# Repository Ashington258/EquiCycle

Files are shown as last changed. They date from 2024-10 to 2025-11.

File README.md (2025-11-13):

# README

本工程是参与全国大学生智能车竞赛室外赛自行车赛道的开源工程。(曾获得智能车竞赛国一)

## 1. 工程结构说明

本项目储存了关于平衡自行车项目所需要的所有源代码，以及硬件架构和软件架构。下面是关于自行车项目的工程结构说明：

1. **main分支**：汇总存放代码
2. **Calculation_Unit分支**：计算单元代码，主要存放关于车道线检测、障碍物识别以及决策类的处理，是系统总计算单元的主要部分。
3. **Control_Unit分支**：控制单元代码，主要存放关于控制模块，负责车身的平衡、转向、前进和后退等运动学操作。
4. **Mechanical_Unit分支**：机械单元分支，主要包含车身的机械结构，用于CNC加工和3D打印等。

> 注：`beta`分支为测试版本代码。

## 2. 实现功能

### 2.1 视觉模块

#### 抗干扰测试（交叉线，阴影）
抗干扰测试

#### 光线变化测试

1. **强光测试**
   强光测试

2. **弱光测试**
   弱光测试

### 2.2 运动学模块

运动学模块
1. 遥感控制/键盘控制
2. 自动控制(PID,LQR)

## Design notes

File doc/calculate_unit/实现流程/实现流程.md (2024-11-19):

# 设计流程

根据架构，工作主要分为Jetson端和Host端的工作

要同时实现Video视频流和Servo控制流，具体程序主要分为Jetson端和Host端，并且需要考虑多线程同步的问题。

- 按任务实现
  - [ ] Video视频流
    - [x] Jetson端
      - [ ] 完成Flask推流
    - [ ] Host端
      - [ ] 完成拉流
  - [ ] Servo控制流
    - [ ] Host端
      - [ ] 计算出的点映射成舵机脉冲
      - [ ] 转化成Servo控制流
      - [ ] UDP发送Servo控制流
    - [ ] Jetson端
      - [ ] 接收Servo控制流
      - [ ] 通过Pyserial转发到串口

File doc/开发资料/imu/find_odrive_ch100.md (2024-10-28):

要将 `/dev/ttyUSB0` 和 `/dev/ttyACM0` 设备与相应的 USB 设备 ID（例如 `10c4:ea60` 和 `1209:0d32`）对应起来，可以使用以下步骤：

### 步骤 1: 确认设备

首先，确保你已经插入了 USB 设备，并使用 `lsusb` 命令确认设备 ID：

```bash
lsusb
```

这将列出所有连接的 USB 设备及其 ID。

### 步骤 2: 使用 `dmesg` 查看设备信息

插入 USB 设备后，使用 `dmesg` 查看设备相关信息：

```bash
dmesg | grep tty
```

这将显示设备连接时的相关信息，包括设备节点（如 `/dev/ttyUSB0` 或 `/dev/ttyACM0`）和设备的 USB ID。

### 步骤 3: 识别设备与串口的对应关系

1. **查看 `dmesg` 输出**：查找在插入设备后产生的输出，通常会显示类似以下格式的信息：

   ```
   [    3.123456] usb 1-1.2: cp210x converter now attached to ttyUSB0
   [    3.123456] usb 1-1.3: pl2303 converter now attached to ttyUSB1
   ```

   这里可以看到 `cp210x` 设备（对应于 `10c4:ea60`）被分配到 `/dev/ttyUSB0`。

2. **使用 `udevadm` 查看设备信息**：你可以使用 `udevadm` 命令来获取更详细的信息：

   ```bash
   udevadm info --name=/dev/ttyUSB0 --attribute-walk
   ```

   这个命令将显示与 `/dev/ttyUSB0` 相关的所有属性，包括 USB ID。

### 步骤 4: 结合信息

通过上述步骤，你可以将设备 ID 与 `/dev/ttyUSB0` 和 `/dev/ttyACM0` 进行对应。例如：

- 如果你看到 `ttyUSB0` 显示的信息中包含 `10c4:ea60`，那么 `/dev/ttyUSB0` 对应于 `CP2102N USB to UART Bridge Controller`。
- 如果 `ttyACM0` 显示的信息中包含 `1209:0d32`，那么 `/dev/ttyACM0` 对应于 `ODrive 3.6 CDC Interface`。

### 示例

假设你在 `dmesg` 输出中看到：

```
[    3.123456] usb 1-1.2: new full-speed USB device number 4 using xhci_hcd
[    3.123456] usb 1-1.2: New USB device found, idVendor=10c4, idProduct=ea60
[    3.123456] usb 1-1.2: cp210x converter now attached to ttyUSB0
```

这表明 `10c4:ea60` 的设备被分配给了 `/dev/ttyUSB0`。

### 总结

通过 `dmesg` 和 `udevadm` 命令，你可以有效地将 `/dev/ttyUSB0` 和 `/dev/ttyACM0` 与相应的 USB 设备 ID 进行对应。如果你有其他问题或需要进一步的帮助，请告诉我！

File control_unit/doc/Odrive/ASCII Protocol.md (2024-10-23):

Here’s a summary of the protocol layers based on the given ASCII protocol, encapsulated in a Python class for ease of use.

### ASCII Protocol Summary
1. **Communication Interfaces**: 
   - USB or UART can be used to communicate with the ODrive. Different commands are sent based on the connection type.

2. **Command Format**:
   - Commands are sent as text-based lines, potentially including an optional GCode-compatible checksum.
   - The format is: `command *checksum ; comment [newline]`.
   - Commands are interpreted when a newline character is encountered.

3. **Command Types**:
   - **Motor Commands**:
     - `t motor destination`: Motor trajectory command.
     - `q motor position velocity_lim torque_lim`: Single setpoint for motor position.
     - `p motor position velocity_ff torque_ff`: Streaming setpoints for motor position.
     - `v motor velocity torque_ff`: Motor velocity command.
     - `c motor torque`: Motor current (torque) command.
   - **Feedback Requests**:
     - `f motor`: Requests motor position and velocity feedback.
   - **Watchdog Update**:
     - `u motor`: Updates the motor watchdog timer.
   - **Parameter Reading/Writing**:
     - `r property`: Read parameter.
     - `w property value`: Write parameter.
   - **System Commands**:
     - `ss`: Save configuration.
     - `se`: Erase configuration.
     - `sr`: Reboot.
     - `sc`: Clear errors.

### Python Encapsulation

The following Python class encapsulates the described ASCII protocol:

```python
import serial

class ODriveAsciiProtocol:
    def __init__(self, port: str, baudrate: int = 115200):
        self.serial = serial.Serial(port, baudrate, timeout=1)

    def send_command(self, command: str):
        # Send command to the ODrive, with newline character
        self.serial.write(f"{command}\n".encode())

    def read_response(self):
        # Read the response from ODrive
        return self.serial.readline().decode().strip()

    def motor_trajectory(self, motor: int, destination: float):
        command = f"t {motor} {destination}"
        self.send_command(command)

    def motor_position(self, motor: int, position: float, velocity_lim: float = None, torque_lim: float = None):
        command = f"q {motor} {position}"
        if velocity_lim is not None:
            command += f" {velocity_lim}"
        if torque_lim is not None:
            command += f" {torque_lim}"
        self.send_command(command)

    def motor_position_stream(self, motor: int, position: float, velocity_ff: float = 0.0, torque_ff: float = 0.0):
        command = f"p {motor} {position} {velocity_ff} {torque_ff}"
        self.send_command(command)

    def motor_velocity(self, motor: int, velocity: float, torque_ff: float = 0.0):
        command = f"v {motor} {velocity} {torque_ff}"
        self.send_command(command)

    def motor_current(self, motor: int, torque: float):
        command = f"c {motor} {torque}"
        self.send_command(command)

    def request_feedback(self, motor: int):
        command = f"f {motor}"
        self.send_command(command)
        return self.read_response()

    def update_watchdog(self, motor: int):
        command = f"u {motor}"
        self.send_command(command)

    def read_parameter(self, property_name: str):
        command = f"r {property_name}"
        self.send_command(command)
        return self.read_response()

    def write_parameter(self, property_name: str, value: float):
        command = f"w {property_name} {value}"
        self.send_command(command)

    def system_command(self, command_type: str):
        valid_commands = {"ss", "se", "sr", "sc"}
        if command_type not in valid_commands:
            raise ValueError(f"Invalid system command: {command_type}")
        self.send_command(command_type)

    def close(self):
        self.serial.close()
```

### Usage Example
```python
# Example usage
odrive = ODriveAsciiProtocol(port='/dev/ttyACM0')
odrive.motor_position(0, -2, velocity_lim=1, torque_lim=0.1)
feedback = odrive.request_feedback(0)
print(f"Motor feedback: {feedback}")
odrive.close()
```

This class provides a Pythonic way to interact with the ODrive via the ASCII protocol, supporting motor control, parameter management, and system operations.

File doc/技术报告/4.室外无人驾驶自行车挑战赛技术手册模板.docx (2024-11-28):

第十九届全国大学生智能汽车竞赛

室外无人驾驶自行车挑战赛

技 术 手 册

学 校：XXXX学院

队伍名称：XX

参赛队员：XX、XX、XX

带队教师：XX、XX

关于技术手册使用授权的说明

本人完全了解全国大学生智能汽车竞赛关于保留、使用技术手册和研究论文的规定，即：参赛技术手册内容著作权归参赛者本人，比赛组委会和赞助公司可以在相关主页上收录并公开参赛作品的设计方案、技术手册、源码以及参赛模型车的视频、图像资料，并将相关内容编纂收录在组委会出版论文集中。

参赛队员签名：

带队教师签名：

日 期： 2024.**.**

（本页需要签字后，替换为扫描页）

## 技术手册撰写注意事项：

了解到实验室队伍老生带新生容易断带、知识不能很好的积累沉淀转化等痛点，本次技术手册的内容更加聚焦于技术总结，知识整理。力图将技术手册打造为老队员、新队员、指导老师之间共用的知识纽带。通过几年的打磨，便于带队老师开设自动化控制、自动驾驶、人工智能、软件编程等相关课程以及开展新队员的筛选工作，便于新队员更快的传承已有的知识储备，使得实验室队伍建设构成闭环。

技术手册内容主要是将自行车作为硬件载体，以自动化控制、自动驾驶、人工智能、软件编程等专业为导向，构建一套用于学习的实验指导书。书写的内容结合车模配套的指导手册、视频资料以及比赛规则。

技术手册书写注意事项如下：

(1) 提交形式为实验指导书+源码；

(2) 所有内容，需要以自行车作为唯一硬件载体；

(3) 提供不少于3个实验，以实验指导书+源码的形式提交；

(4) 裁判将结合实验难易程度、书写清晰度、实验个数、实验间是否有关联性等多种因素，决定本技术手册的优劣。

技术手册总分10分，评判标准如下：

(1)每个实验最高分5分，总体不少于2个实验；

(2)每个实验得分根据实验难易程度、书写清晰度、实验间是否有关联性、创新性等因素进行判定；

(3)若书写多于2个实验，逐个实验判分后，以分数最高的2个实验的成绩加和作为最终成绩。

### 目录（供参考）

实验一 单片机设计原理 2

实验二 供电系统设置 4

实验三 电机调节步骤及参数解析 6

实验四 PID算法调试 8

实验五 激光雷达数据结构分析及滤波 10

实验六 视觉功能调试 12

实验七 opencv数据处理 14

实验八 机器人运动学平台 16

(以上目录仅供参考，具体实验名称及实验内容由学生自主设定)

实验案例书写具体要求如下：

实验案例需言简意赅，便于后续师弟师妹消化传承；

实验案例撰写可自行创新发挥，新颖的案例更加容易获得高分；

每个实验需要包含实验目的、实验内容、实验器材、实验原理、实验步骤这几部分；

实验目的：参考模板，提炼若干条

实验内容：针对实验目的，开展的具体操作总结

实验器材：罗列实验中用到的器材设备、传感器、工具、测量仪器等

实验原理：描述实验中硬件实现原理、物理相关基础、算法实现原理等

实验步骤：实验开展过程中具体的运行指令、操作方式、测试方式、代码讲解等

### 实验五 激光雷达数据结构分析及滤波(参考样例)

#### 实验目的：

1、熟悉激光雷达数据结构；

2、了解激光雷达数据的处理方法；

3、熟练掌握laser_filters功能包的使用；

#### 实验内容：

1、获取并分析激光雷达数据；

2、对激光雷达数据进行滤波处理。

#### 实验仪器：

ROS智能车、激光雷达、电压表

#### 实验原理：

利用laser_filters功能包，对雷达数据进行处理，得到需要的滤波后的雷达数据。

#### 实验步骤：

<1> 启动雷达，并获取雷达数据(需要先编译我的功能包，并加入环境变量)

$ roslaunch ls0lb_v2 ls01b_v2.launch

启动后的效果如下图所示，这个时候就启动了雷达节点和滤波节点，具体为什么会启动，已经如何配置launch文件里那些参数，后面会讲到。首先我们先来看一下雷达的原始数据，分析一下雷达数据结构。

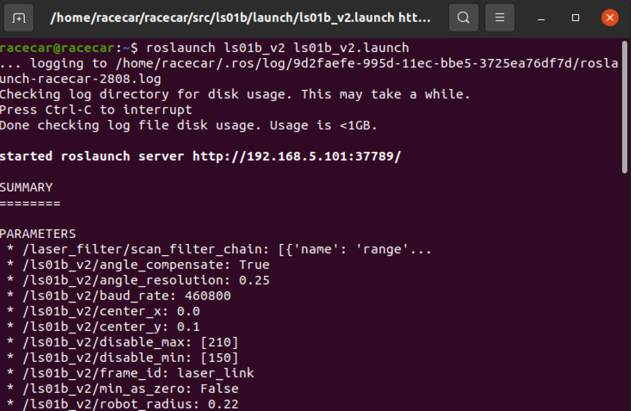
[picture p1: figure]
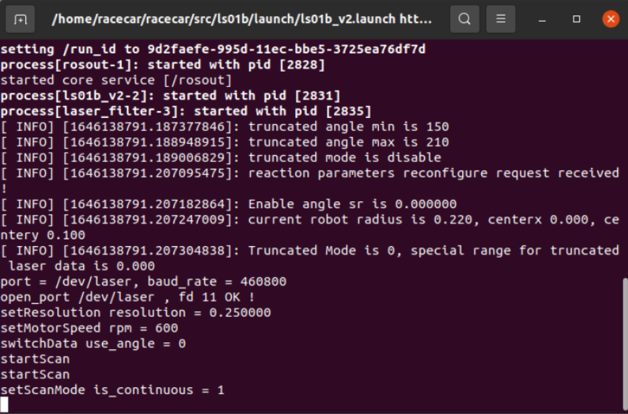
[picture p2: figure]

<2> 打印雷达数据消息，并分析雷达数据(新开一个终端输入下面命令)

$ rostopic echo /scan

运行后会如下图所示，不断打印雷达数据。

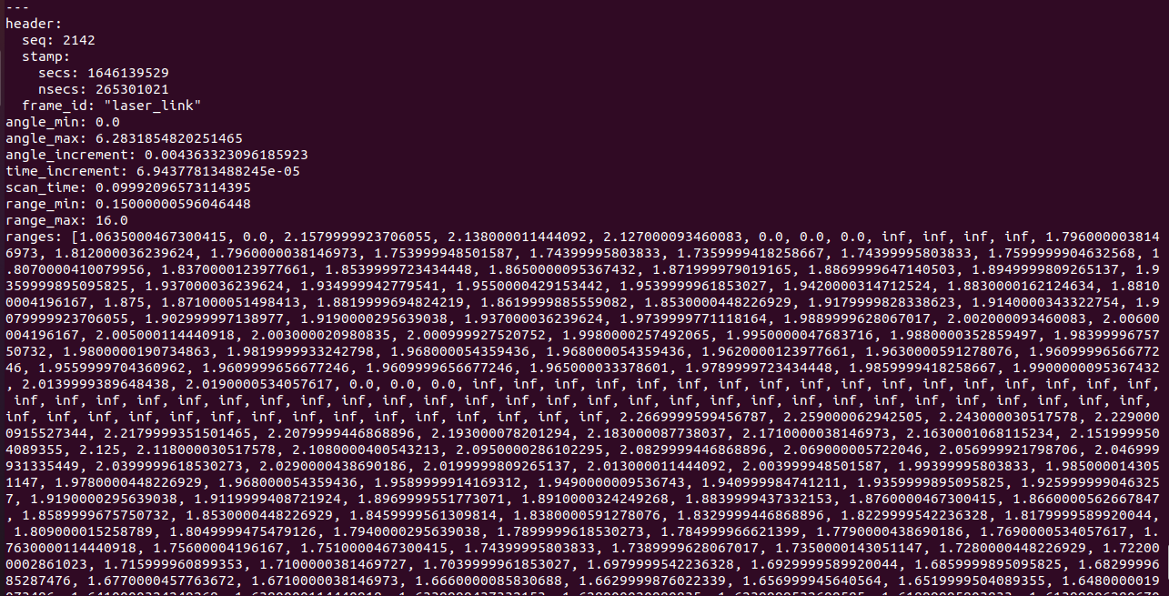
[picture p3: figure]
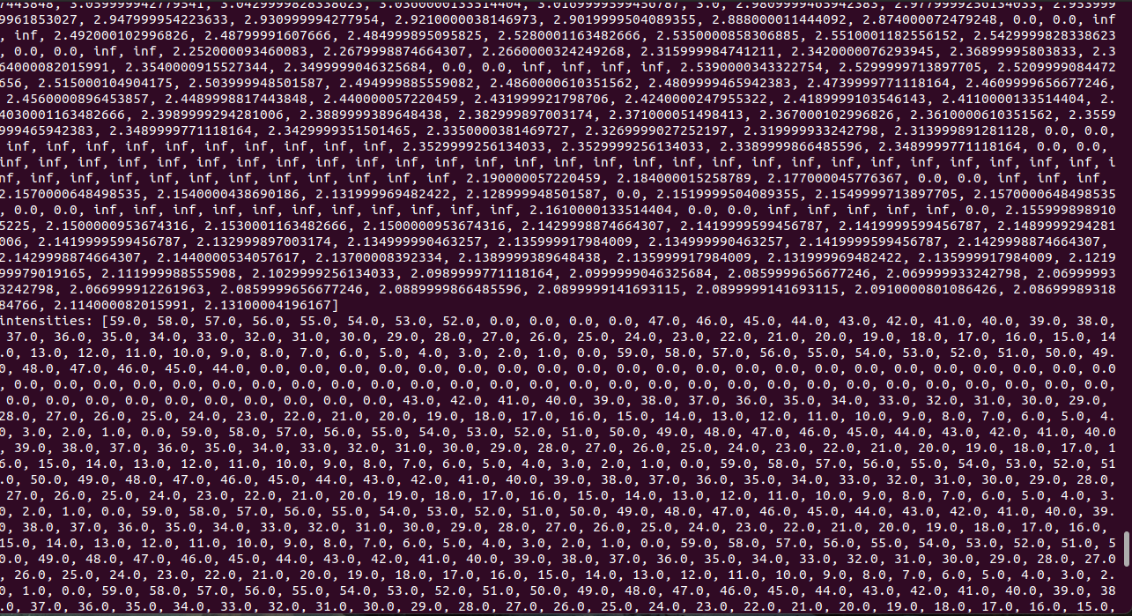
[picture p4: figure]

下面我们来看一下雷达数据结构：

激光雷达是避障与SLAM常用的装备，ROS中也对激光雷达作出了相应的支持，各个厂家也有不少提供了自己的ROS库供开发者使用，使得无论是初学者还是大神们都能轻松愉快的使用激光雷达为自己的机器人导航。

ROS中的sensor_msgs/LaserScan提供了最基础的针对一线激光雷达消息格式：

# 一线激光雷达的一次扫描

Header header # timestamp是扫描中第一束激光的获取时间

# 角度环绕Z轴（Z轴为激光雷达正上方），逆时钟方向增加，0度角指向X轴

float32 angle_min # 扫描的起始角度 [rad]

float32 angle_max # 扫描的结束角度 [rad]

float32 angle_increment # 每次测量间的角度差 [rad]

float32 time_increment # 每次测量间的时间差 [seconds]

# 这个数值会用来生成点云（而不是scan_time）

float32 scan_time # 每次扫描的时间差 [seconds]

# 这个时间差是每次激光发射的时间差，上面那个是每次接收（测量）的时间差

float32 range_min # 距离最小值 [m]

float32 range_max # 距离最大值 [m]

float32[] ranges # 距离数据 [m]

float32[] intensities # 强度数据 [单位视设备标定]

#如果设备不产生强度数据，则该数据为空

对应前面的雷达数据，我们可以将sensor_msgs/LaserScan消息和智能车雷达数据一一对应起来，我重点讲的是range数据，因为后面实验三会用到。

range是数组，数组的长度越长，说明激光雷达的精度越高，咱们的智能车的range数组长度是1140，也就是一周每一度都有4份距离信息。

range数组是如何和角度对应的呢？range[0]对应的角度就是激光雷达的零点方向（一般为激光雷达的正前方），后面数据rangep[1]、range[2]……依次为沿激光雷达逆时针方向对应角度的距离数据。

<3> 使用laser_filters对雷达数据进行滤波

$ laser_filters的wiki页 (http://wiki.ros.org/laser_filters)

http://wiki.ros.org/laser_filters

在yaml文件里面定义了很多laser_filters消息的参数后，通过启动laser_filters节点完成激光雷达消息的过滤。其中scan_to_scan_filter_chain提供了从初始扫描到过滤后扫描的流程：

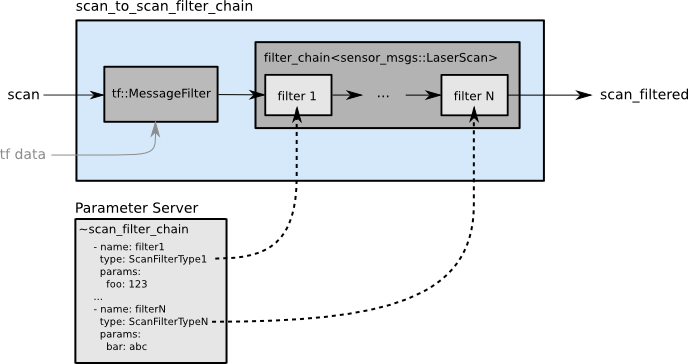
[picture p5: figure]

而scan_to_cloud_filter_chain提供了从scan消息生成过滤后的点云的流程：

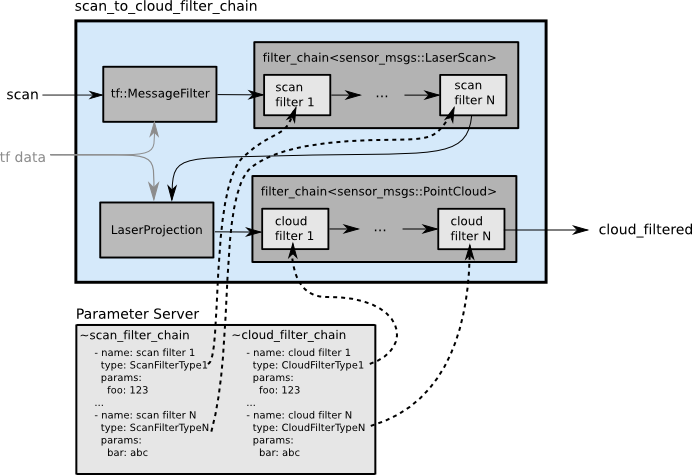
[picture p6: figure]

这两类的示例yaml和launch都可以在上面提供的wiki页找到，很有参考价值的（基本上拷下来调调参数就能用了）设置参数放在yaml里，消息转换和参数加载放在launch里。

<4> laser_filters常用参数类型：

1.InterpolationFilter

将扫描中出现的异常数据通过使用两侧的正常数据进行补齐，效果如下：

.....`..... => InterpolationFilter => ...........

参数设置示例：

scan_filter_chain:

- name: interpolation

type: InterpolationFilter

2.LaserScanIntensityFilter

强度值过滤器，将超出范围的扫描结果中的距离结果设为最大距离+1，从而将结果标记为异常。这思路有点迷，参数有三个：

lower_threshold (double) 最小阈值

upper_threshold (double) 最大阈值

disp_histogram (int) 是否输出柱状图(°Д°)居然有这功能，牛逼

参数设置示例：

scan_filter_chain:

- name: intensity

type: LaserScanIntensityFilter

params:

lower_threshold: 8000

upper_threshold: 100000

disp_histogram: 0

3. LaserScanRangeFilter：

距离值过滤器，会把超过设定范围阈值的数据改为NaN或根据设定进行更改。另外可以读取scan消息中的范围阈值信息。

lower_threshold (double) 最小阈值

upper_threshold (double) 最大阈值

use_message_range_limits (bool) 是否使用scan消息中的阈值信息，默认为false

lower_replacement_value (double) 将小于最小阈值的数据改为该值，默认NaN

upper_replacement_value (double) 将大于最大阈值的数据改为该值，默认NaN

参数设置示例：

scan_filter_chain:

- name: range

type: LaserScanRangeFilter

params:

use_message_range_limits: false

lower_threshold: 0.3

upper_threshold: .inf

lower_replacement_value: -.inf

upper_replacement_value: .inf

4. LaserScanAngularBoundsFilter

将设定的角度外的扫描数据删除。

lower_angle (double) 最小角度（rad）

upper_angle (double) 最大角度（rad）

参数设置示例：

scan_filter_chain:

- name: angle

type: LaserScanAngularBoundsFilter

params:

lower_angle: -1.57

upper_angle: 1.57

5. 其他参数

LaserScanBoxFilter 无视一个区块内的数据（常用于无视机器人本体对激光雷达数据的干扰）

LaserScanAngularBoundsFilterInPlace 不会删除目标角度扇区外的数据，但会把对应扫描的距离值设为最大距离阈值+1

ScanShadowsFilter 针对物体边沿的扫描和识别

LaserArrayFilter 使用数学过滤器对距离和强度进行过滤

<5> 该方案采用的滤波参数详解：

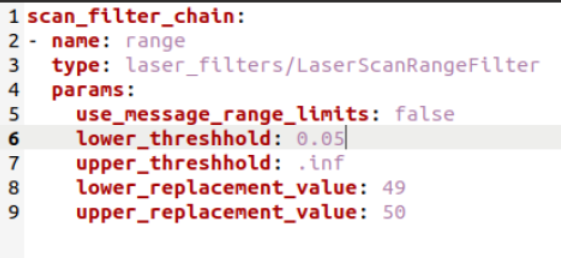
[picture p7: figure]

本方案采用的laser_filters滤波参数如上图所示。最小阈值设置为了0.05，最大阈值设置为了.inf。也就是小于等于0.05的距离会变成49，大于等于.inf的会变成50。

下面我们再来看一下launch文件是如何编写的。

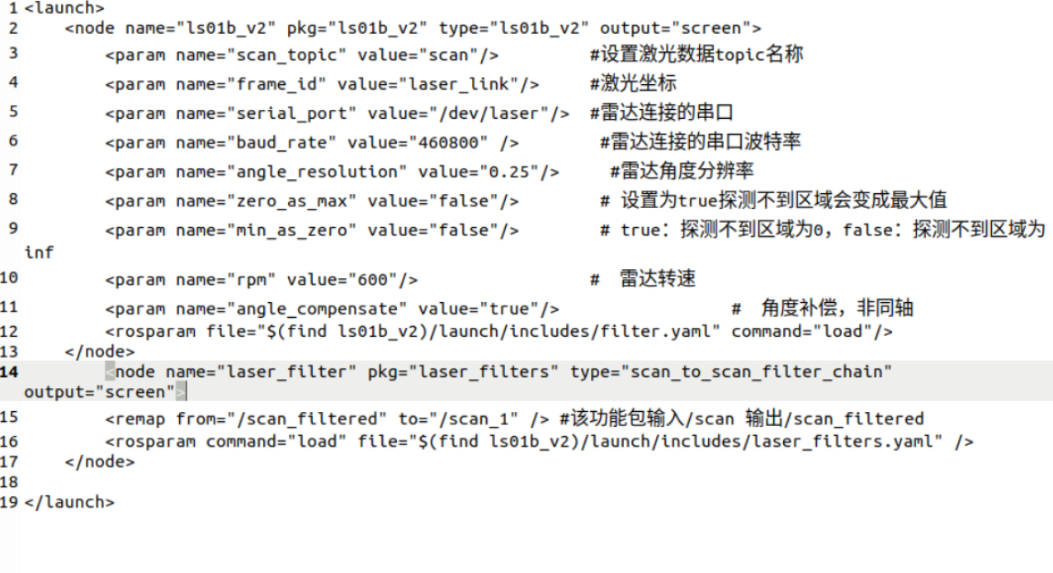
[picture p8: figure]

如图所示，雷达滤波功能包订阅的话题名称是/scan话题，对/scan话题数据滤波处理后发布的话题是/scan_filtered，launch文件的第15行将话题名/scan_filtered重映射为/scan_1。

输入如下命令，查看滤波前的雷达数据/scan和滤波后的雷达数据/scan_q

$ roslaunch ls0lb_v2 ls01b_v2.launch (终端1)

$ rostopic echo /scan (终端2)

$ rostopic echo /scan_1 (终端3)

_

这个时候对比观察可以看出，/scan_1的雷达数据是按照我们设置滤波后的数据。

为什么我们要把小于等于0.05的数据变成49，把大于等于.inf的数据变成50呢？下面的实验三会详细讲到，其目的就是为了方便后面利用雷达数据定位到锥桶位置。

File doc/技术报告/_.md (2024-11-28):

# 技术报告：机器人运动学分析与视觉处理平台

---

## 1 视觉处理平台

### 1.1 系统架构

视觉处理平台的主要任务是为小车提供精准的车道检测与跟踪能力。该平台架构包括从图像采集到车道线检测、追踪到控制输出的一整套系统，通过硬件加速实现高效性能和稳定的实时处理。

#### 1.1.1 硬件配置

- **处理器平台**：NVIDIA Jetson TX2，用于执行GPU加速的深度学习推理。
- **摄像头**：高分辨率车载摄像头，适应不同光照环境，捕捉车道图像。
- **辅助硬件**：CUDA和TensorRT优化YOLO模型，提升处理速度。

#### 1.1.2 软件架构

- **操作系统**：Ubuntu 18.04，配置支持ROS和OpenCV。
- **深度学习框架**：PyTorch与TensorFlow用于训练和部署YOLO。
- **优化工具**：TensorRT对YOLO模型进行加速，提升处理效率。

### 1.2 视觉处理流程

#### 1.2.1 车道线检测

利用YOLOv5网络执行实例分割，实现车道区域边缘检测。
  
  - **输入**：车载摄像头实时图像。
  - **处理**：YOLOv5模型检测车道区域的边界框。
  - **输出**：车道边界框坐标及周围物体（如车辆、障碍物）的分类与位置。

#### 1.2.2 Skeleton化与边缘细化

通过Skeleton化算法提取车道轮廓，以进一步细化车道主方向。
  
  - **输入**：YOLO分割结果。
  - **处理**：Skeleton化算法生成车道骨架。
  - **输出**：细化后的车道骨架图。

#### 1.2.3 骨架点拟合与车道线提取

使用最小二乘法或RANSAC算法对骨架点拟合，生成精确的车道线模型。
  
  - **输入**：骨架图与提取的骨架点。
  - **处理**：拟合算法生成车道曲线。
  - **输出**：车道线的数学模型。

#### 1.2.4 车道线偏差计算与控制

计算拟合车道线与预期行驶路径的偏差，得到车辆中心的偏离距离。

  - **输入**：拟合车道线与预期路径。
  - **处理**：计算水平或垂直方向的偏差值。
  - **输出**：偏差值，用于运动控制。

### 1.3 控制系统

#### 1.3.1 控制算法

- **PID控制**：基于偏差值，调整小车转向和速度，确保其行驶在车道内。

  - **输入**：车道偏差值。
  - **处理**：PID控制器输出转向角度与速度。
  - **输出**：小车转向与速度调整。

#### 1.3.2 实时性与优化

- **实时处理**：通过TensorRT加速YOLO模型，Jetson TX2的GPU加速每秒多帧图像处理。

### 1.4 系统评估与优化

#### 1.4.1 性能评估

- **准确性**：在不同光照、天气及道路标线条件下测试车道线检测精度。
- **实时性**：确保100ms以内完成检测与控制输出。

#### 1.4.2 系统优化

- **算法优化**：采用轻量化YOLO模型，降低计算复杂度。
- **硬件加速**：利用Jetson TX2的CUDA和TensorRT，加速深度学习推理。

### 1.5 总结

该视觉处理平台通过YOLO网络结合Skeleton化算法，实现精准车道信息提取，利用PID算法进行车辆控制。其实时性与高效性支持复杂环境下的自动驾驶应用。

---

## 2 机器人运动学分析

### 2.1 模型建立

采用拉格朗日方法，通过系统的动能与势能导出运动方程。

#### 2.1.1 拉格朗日方程

拉格朗日方程为：

$$
\frac{d}{dt} \frac{\partial \mathcal{L}}{\partial \dot{\mathbf{q}}} - \frac{\partial \mathcal{L}}{\partial \mathbf{q}} = 0
$$

其中：
- 拉格朗日量为动能与势能的差，\(\mathcal{L} = T - V\)。
- 广义坐标 \(\mathbf{q} = (q_1, q_2, \dots, q_N)\) 和广义速度 \(\dot{\mathbf{q}} = (\dot{q}_1, \dot{q}_2, \dots, \dot{q}_N)\)。

#### 2.1.2 动能计算

系统动能来自车体和飞轮：

$$
T = T_1 + T_2 = \frac{1}{2} \left( \dot{\alpha}^2 (m_1 l_1^2 + m_2 l_2^2) + J_1 \dot{\alpha}^2 + J_2 (\dot{\alpha} + \dot{\beta})^2 \right)
$$

其中：
- **飞轮动能** \(T_2 = \frac{1}{2} m_2 \dot{\alpha}^2 l_2^2 + \frac{1}{2} J_2 (\dot{\alpha} + \dot{\beta})^2\)
- **车体动能** \(T_1 = \frac{1}{2} m_1 \dot{\alpha}^2 l_1^2 + \frac{1}{2} J_1 \dot{\alpha}^2\)

#### 2.1.3 势能计算

系统势能为：

$$
V = V_1 + V_2 = g \cos \alpha (m_1 l_1 + m_2 l_2)
$$

#### 2.1.4 拉格朗日函数

拉格朗日函数为：

$$
\mathcal{L} = \frac{1}{2} \dot{\alpha}^2 (m_1 l_1^2 + m_2 l_2^2) + \frac{1}{2} \left( J_1 \dot{\alpha}^2 + J_2 (\dot{\alpha} + \dot{\beta})^2 \right) - g \cos \alpha (m_1 l_1 + m_2 l_2)
$$

### 2.2 运动方程

#### 2.2.1 车体运动方程

$$
\ddot{\alpha} (m_1 l_1^2 + m_2 l_2^2) + J_1 \ddot{\alpha} + J_2 (\ddot{\alpha} + \ddot{\beta}) - g \sin \alpha (m_1 + m_2) = 0
$$

描述了车体平衡角 \(\alpha\) 的动态变化，涉及质量、惯性矩及重力影响。

#### 2.2.2 飞轮运动方程

$$
J_2 (\ddot{\alpha} + \ddot{\beta}) = M
$$

该方程描述了飞轮角度 \(\beta\) 的变化，\(M\) 为飞轮的外部力矩。

### 2.3 约束条件

实际系统的约束条件为：

$$
\begin{cases}
\mathcal{Q}_\alpha = 0 \\
\mathcal{Q}_\beta = 0
\end{cases}
$$

### 2.4 模型求解

根据运动方程和约束条件，使用数值方法（如Euler法或Runge-Kutta法）对系统动态进行仿真，结果用于设计控制系统，确保稳定运行。

\[
\begin{cases}
\ddot{\alpha}(m_1 l_1^2 + m_2 l_2^2) + J_1 \ddot{\alpha} + J_2 \left( \ddot{\alpha} + \ddot{\beta} \right) - g \sin \alpha (m_1 + m_2) = 0 \\
J_2 \left( \ddot{\alpha} + \ddot{\beta} \right) = M
\end{cases}
\]

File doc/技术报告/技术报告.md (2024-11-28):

# 技术报告

## 1 视觉处理平台

- **使用算法**
  - 首先使用YOLO网络进行Instance segmentation
  - 再使用Skeleton骨架化方法细化segmentation边缘
  - 对骨架点进行拟合，得到车道线
  - 对拟合结果与期望行驶线求偏差并算数平均作为输出，让小车保持再车道线内

## 3 机器人运动学分析

# 运动学分析

## 1 模型建立

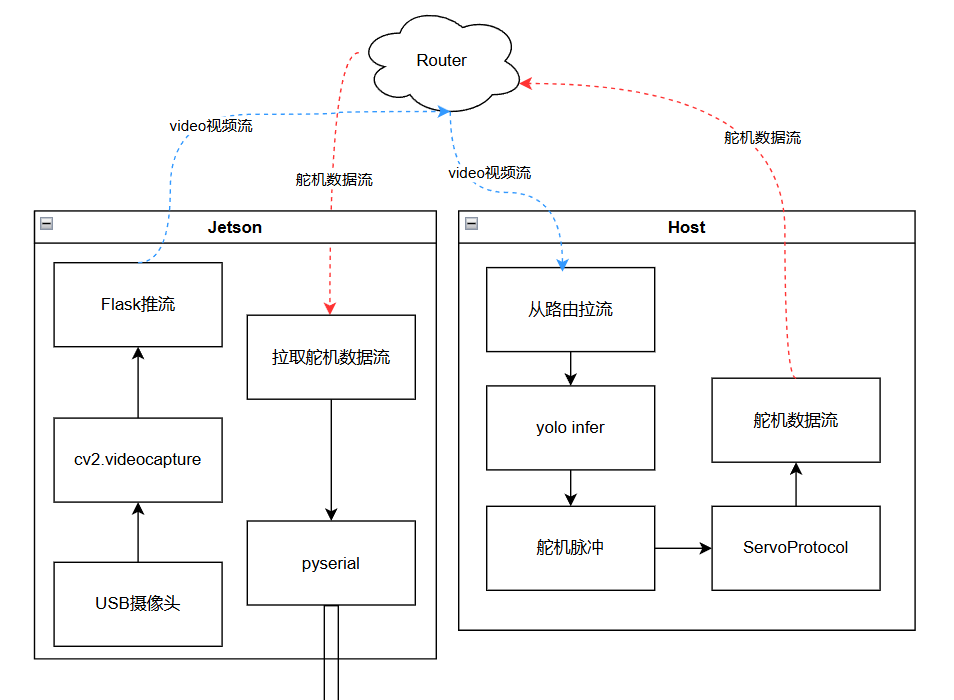
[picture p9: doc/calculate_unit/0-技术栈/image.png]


### 1.1 Lagrange Analysis

#### 1.1.1 **Lagrange Equation**

$$\frac d{dt}\frac{\partial\mathcal{L}}{\partial\dot{\mathbf{q}}}-\frac{\partial\mathcal{L}}{\partial\mathbf{q}}=\mathbf{0}$$

- Lagrange 量：$\mathcal{L}(\mathbf{q}, \dot{\mathbf{q}}, t)$
- 广义坐标：$\mathbf{q}=(q_1,q_2,\ldots,q_N)$
- 广义速度：$\dot{\mathbf{q}}=(\dot{q}_1,\dot{q}_2,\ldots,\dot{q}_N)$

#### 1.1.2 **Lagrange Function**

$$L=T-V$$

#### 1.1.3 **模型建立**

1. 坐标选择
   选择广义坐标$q(\alpha,\beta)$
   - $\alpha$：balance angle
   - $\beta$：fly-wheel angle
2. Lagrange 方程计算
   1. 动能计算
      1. 总动能：$T=T_{1}+T_{2}=\frac{1}{2}\Bigg(\dot{\alpha}^{2}\Big(m_{1}l_{1}^{2}+m_{2}l_{2}^{2}\Big)+J_{1}\dot{\alpha}^{2}+J_{2}\Bigg(\dot{\alpha}+\dot{\beta}\Bigg)^{2}\Bigg)$
      2. 飞轮:$T_{2}=\frac{1}{2}m_{2} \dot{\alpha}^{2} l_{2}^{2}+\frac{1}{2}J_{2}\biggl(\dot{\alpha}+\dot{\beta}\biggr)^{2}$
         1. 
      3. 车体:$T_{1}=\frac{1}{2}m_{1} \dot{\alpha}^{2}l_{1}^{2}+\frac{1}{2}J_{1} \dot{\alpha}^{2}$
   2. 势能计算
      1. 总势能：$V=V_{1}+V_{2}=gcos\alpha(m_{1}l_{1}+m_{2}l_{2})$
         1. 自行车车体势能：$V_{1}=gcos\alpha m_{1}l_{1}$
         2. 飞轮势能：$V_{2}=gcos\alpha m_{2}l_{2}$
3. Lagrange 函数计算
   1. $$L=T-V=\frac{1}{2}\dot{\alpha}^{2}\Big(m_{1}l_{1}^{2}+m_{2}l_{2}^{2}\Big)+\frac{1}{2}\Bigg(J_{1}\dot{\alpha}^{2}+J_{2}\Bigg(\dot{\alpha}+\dot{\beta}\Bigg)^{2}\Bigg)-g\cos\alpha\big(m_{1}l_{1}+m_{2}l_{2}\big)$$
4. 模型求解
   1. 约束条件：$\begin{cases}\mathcal{Q}_\alpha=0\\\mathcal{Q}_\beta=0&\end{cases}$
   2. \[
\begin{cases}
\ddot{\alpha}(m_1 l_1^2 + m_2 l_2^2) + J_1 \ddot{\alpha} + J_2 \left( \ddot{\alpha} + \ddot{\beta} \right) - g \sin \alpha (m_1 + m_2) = 0 \\
J_2 \left( \ddot{\alpha} + \ddot{\beta} \right) = M
\end{cases}
\]

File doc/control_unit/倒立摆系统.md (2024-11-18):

倒立摆的数学模型通常是通过推导倒立摆的动力学方程来描述的。以下是最常见的倒立摆模型，假设系统包括一个摆杆（刚性杆）和一个能够左右移动的小车。

### 1. 变量定义

- \( x \): 小车的位置
- \( \theta \): 摆杆的角度，相对于竖直方向
- \( m \): 摆杆的质量
- \( M \): 小车的质量
- \( l \): 摆杆的长度
- \( g \): 重力加速度
- \( u \): 小车的外力（控制输入）

### 2. 动力学方程

倒立摆问题可以通过拉格朗日方程求解。首先，需要写出小车和摆杆的动能和势能，然后得到拉格朗日函数（Lagrangian）。

- **小车的动能** \( T_{\text{cart}} \)：
  \[
  T_{\text{cart}} = \frac{1}{2} M \dot{x}^2
  \]

- **摆杆的动能** \( T_{\text{pendulum}} \)：
  \[
  T_{\text{pendulum}} = \frac{1}{2} m \left( \dot{x}^2 + (l \dot{\theta})^2 + 2l \dot{x} \dot{\theta} \cos\theta \right)
  \]

- **小车和摆杆的总动能**：
  \[
  T = T_{\text{cart}} + T_{\text{pendulum}}
  \]

- **摆杆的势能** \( U \)：
  \[
  U = - m g l \cos \theta
  \]

根据拉格朗日方程 \( L = T - U \)，并通过求解欧拉-拉格朗日方程 \( \frac{d}{dt} \left( \frac{\partial L}{\partial \dot{q}_i} \right) - \frac{\partial L}{\partial q_i} = Q_i \) （其中 \( Q_i \) 是广义力），我们可以得到倒立摆的运动方程。

### 3. 运动方程

最终得到的倒立摆的运动方程如下：

\[
(M + m) \ddot{x} + m l \ddot{\theta} \cos \theta - m l \dot{\theta}^2 \sin \theta = u
\]

\[
m l \ddot{x} \cos \theta + m l^2 \ddot{\theta} + m g l \sin \theta = 0
\]

这是一组耦合的二阶微分方程，描述了小车的加速度 \( \ddot{x} \) 和摆杆的加速度 \( \ddot{\theta} \) 之间的关系。

### 4. 线性化（当 \(\theta\) 小时）

为了简化控制问题，通常我们会在倒立摆的平衡点（\(\theta = 0\)）附近对系统进行线性化。假设摆杆角度小，\(\sin \theta \approx \theta\) 和 \(\cos \theta \approx 1\)，我们得到以下线性近似的方程：

\[
(M + m) \ddot{x} + m l \ddot{\theta} = u
\]

\[
m l \ddot{x} + m l^2 \ddot{\theta} + m g \theta = 0
\]

通过求解这两个方程，可以得到系统的状态空间表示，通常用来设计控制器。

### 5. 状态空间模型（线性化）

将上面的方程线性化后，可以得到倒立摆系统的状态空间模型。定义状态变量：

\[
x_1 = x, \quad x_2 = \dot{x}, \quad x_3 = \theta, \quad x_4 = \dot{\theta}
\]

系统的状态空间形式为：

\[\begin{bmatrix}\dot{x_1}\\\dot{x_2}\\\dot{x_3}\\\dot{x_4}\end{bmatrix}=\begin{bmatrix}0&1&0&0\\0&0&\frac{ml}{M+m}&0\\0&0&0&1\\0&0&\frac{g(M+m)}{l(M+m)}&0\end{bmatrix}\begin{bmatrix}x_1\\x_2\\x_3\\x_4\end{bmatrix}+\begin{bmatrix}0\\\frac{1}{M+m}\\0\\-\frac{1}{l(M+m)}\end{bmatrix}u\]

这个状态空间模型可以用于设计倒立摆的反馈控制算法，如LQR（线性二次调节器）等。

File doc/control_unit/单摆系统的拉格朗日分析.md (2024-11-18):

牛顿力学和拉格朗日力学是经典力学中的两种主要描述物理系统运动的方法，它们各自有不同的优势和应用场景。下面我们将从简单的物理模型出发，对比这两种方法，并提供拉格朗日力学的使用教程。

### 牛顿力学

牛顿力学基于牛顿的三大运动定律，通常通过直接描述物体的受力情况来推导物体的运动方程。牛顿力学的基本形式是：

\[
\vec{F} = m \vec{a}
\]

其中，\(\vec{F}\) 是作用在物体上的总力，\(m\) 是物体的质量，\(\vec{a}\) 是物体的加速度。牛顿力学常用于解决涉及力的直接计算问题，但在一些复杂系统中，尤其是约束条件较多的系统（例如带有非线性约束的系统），牛顿力学的处理比较困难。

### 拉格朗日力学

拉格朗日力学是一种更为广泛的理论框架，特别适用于具有约束条件的系统。它通过引入拉格朗日量 \(L\) 来描述系统的运动，定义为动能和势能之差：

\[
L = T - V
\]

其中，\(T\) 是系统的动能，\(V\) 是系统的势能。拉格朗日力学的核心思想是通过求解拉格朗日方程来获得系统的运动方程。拉格朗日方程的形式为：

\[
\frac{d}{dt} \left( \frac{\partial L}{\partial \dot{q}_i} \right) - \frac{\partial L}{\partial q_i} = 0
\]

其中，\(q_i\) 是广义坐标（通常是描述系统位置的变量），\(\dot{q}_i\) 是广义速度（即广义坐标的时间导数）。

### 牛顿力学与拉格朗日力学的对比

1. **描述方式**：
   - 牛顿力学直接描述力和加速度的关系，适合处理力学问题。
   - 拉格朗日力学通过动能和势能的差来描述系统，尤其适用于处理约束条件（例如滑轮、绳索等系统）和复杂的多体问题。

2. **约束条件**：
   - 牛顿力学在处理约束力时需要明确列出所有力，并考虑约束力对系统的影响。
   - 拉格朗日力学通过广义坐标的引入，能够自然地处理有约束的系统（例如在机械系统中，坐标可以选择为约束后的自由度）。

3. **适用性**：
   - 牛顿力学更直观，适用于力和加速度可以直接测量的系统。
   - 拉格朗日力学在处理具有复杂约束或多自由度的系统时，能够更简洁地推导出运动方程。

### 拉格朗日力学的使用教程

我们通过一个简单的物理模型来介绍如何使用拉格朗日力学。

#### 例子：单摆系统

假设有一个简单的单摆，摆球的质量为 \(m\)，摆长为 \(l\)，摆动角度为 \(\theta\)，重力加速度为 \(g\)。该系统只有一个自由度，即摆动的角度 \(\theta\)。

1. **选择广义坐标和速度**：
   - 选择广义坐标 \(q = \theta\)（即摆球的角度）。
   - 广义速度 \(\dot{q} = \dot{\theta}\) 是角速度。

2. **计算动能 \(T\)**：
   摆球的动能由其线性速度给出，线速度为 \(v = l \dot{\theta}\)，因此动能为：
   \[
   T = \frac{1}{2} m v^2 = \frac{1}{2} m l^2 \dot{\theta}^2
   \]

3. **计算势能 \(V\)**：
   由于重力的作用，势能 \(V\) 由物体的高度决定，高度为 \(h = l (1 - \cos\theta)\)，因此势能为：
   \[
   V = m g h = m g l (1 - \cos\theta)
   \]

4. **构造拉格朗日量 \(L\)**：
   拉格朗日量是动能与势能之差：
   \[
   L = T - V = \frac{1}{2} m l^2 \dot{\theta}^2 - m g l (1 - \cos\theta)
   \]

5. **推导拉格朗日方程**：
   使用拉格朗日方程：
   \[
   \frac{d}{dt} \left( \frac{\partial L}{\partial \dot{\theta}} \right) - \frac{\partial L}{\partial \theta} = 0
   \]
   首先计算 \(\frac{\partial L}{\partial \dot{\theta}}\) 和 \(\frac{\partial L}{\partial \theta}\)：
   \[
   \frac{\partial L}{\partial \dot{\theta}} = m l^2 \dot{\theta}
   \]
   \[
   \frac{\partial L}{\partial \theta} = m g l \sin\theta
   \]

   然后求导数：
   \[
   \frac{d}{dt} \left( m l^2 \dot{\theta} \right) = m l^2 \ddot{\theta}
   \]

   将这些代入拉格朗日方程得到：
   \[
   m l^2 \ddot{\theta} + m g l \sin\theta = 0
   \]
   简化后得到单摆的运动方程：
   \[
   \ddot{\theta} + \frac{g}{l} \sin\theta = 0
   \]

这是一个简单的二阶非线性微分方程，描述了单摆的运动。

### 总结

拉格朗日力学通过构造拉格朗日量来描述物理系统的动力学行为，尤其适用于处理复杂约束和多自由度的系统。使用拉格朗日力学的关键步骤是：选择合适的广义坐标和广义速度，计算动能和势能，构造拉格朗日量，并通过拉格朗日方程推导运动方程。对于复杂系统，拉格朗日方法往往比牛顿方法更为简洁和高效。

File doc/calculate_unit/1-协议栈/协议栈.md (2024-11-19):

# 多数据流局域网平台协议栈

构建舵机和视频的完整协议栈需要根据实时性需求、网络特性和传输稳定性，合理设计每层的功能。以下是针对舵机控制数据和视频流的完整协议栈设计。

---

## **舵机控制数据协议栈**

### **应用层**
- **功能**：
  - 定义舵机控制指令格式。
  - 解析接收数据并执行相应的控制逻辑。
- **数据帧格式**（用户之前提到的帧格式为例）：
  ```
  +------------+-----------------+-------+------------+
  | Frame Head | Control Data    | CRC   | Frame Tail |
  +------------+-----------------+-------+------------+
  ```
  - **Frame Head**: 固定标志位 (0x30)。
  - **Control Data**: 舵机控制指令，使用小端模式存储，具体值由协议定义（如舵机角度或脉宽值）。
  - **CRC**: 校验字段，用于错误检测。
  - **Frame Tail**: 固定标志位 (0x40)。

### **传输层**
- **协议**：UDP
  - 选择 UDP 是因为其低延迟特性，适用于实时控制需求。
- **优化措施**：
  - 数据包长度控制在 MTU 之内，避免分片。
  - 增加简单的 ACK 机制（可选），用于确认关键指令是否到达。

### **网络层**
- **协议**：IPv4
  - 使用私有 IP 地址（如 192.168.x.x）。
  - 在局域网环境中，使用静态 IP 或动态分配（DHCP）。

### **数据链路层**
- **协议**：以太网（Ethernet）
  - 数据帧通过局域网交换机传输。
  - 优先使用千兆以太网以降低延迟。

---

## **视频流协议栈**

### **应用层**
- **协议**：HTTP (Flask) 或 WebSocket
  - **HTTP**：
    - 使用 Flask 的 `Response` 方法实现视频流。
    - 视频数据以 `multipart/x-mixed-replace` 的方式连续传输。
  - **WebSocket**：
    - 提供全双工通信，降低延迟。
    - 适用于实时性要求更高的场景。
  - **数据格式**：
    - **MJPEG**：每一帧编码为 JPEG 格式，适合传输动态帧。
    - **H.264/HEVC**：适合带宽有限但延迟较高的情况。

### **传输层**
- **协议**：TCP 或 UDP
  - **TCP**（适用于 HTTP）：
    - 确保数据完整性，适合视频流传输。
    - 避免丢帧导致的图像损坏。
  - **UDP**（适用于 WebSocket 或 RTSP）：
    - 更低的传输延迟，适合实时视频。
    - 可通过丢帧策略容忍少量数据丢失。

### **网络层**
- **协议**：IPv4
  - 与舵机控制数据共用网络层配置。
  - 如果使用多设备，确保路由器的流量分配均衡。

### **数据链路层**
- **协议**：以太网（Ethernet）
  - 和舵机控制数据使用相同的局域网。
  - 优先分配带宽给视频流，避免视频卡顿。

---

## **协议栈对比与整合**

| **层次** | **舵机控制数据** | **视频流** |
| --- | --- | --- |
| **应用层** | 自定义协议（控制指令 + 校验） | HTTP/Flask, WebSocket, RTSP |
| **传输层** | UDP | TCP（HTTP）/UDP（WebSocket/RTSP） |
| **网络层** | IPv4 | IPv4 |
| **数据链路层** | 以太网（Ethernet） | 以太网（Ethernet） |

---

## **实现注意事项**
1. **独立传输通道**：
   - 视频流和舵机控制数据分开传输，避免相互干扰。
   - 舵机使用固定的 UDP 端口，视频流使用 HTTP/RTSP 的端口。
2. **数据优先级管理**：
   - 路由器或交换机上设置 QoS（Quality of Service），优先保证舵机控制数据的实时性。
3. **同步机制**：
   - 在应用层通过时间戳同步视频帧和舵机控制指令。
4. **网络性能监控**：
   - 使用工具（如 `tcpdump` 或 Wireshark）分析延迟、丢包率等。

这种协议栈设计能有效满足视频流和舵机控制数据的实时传输需求，同时具备灵活性和可扩展性。

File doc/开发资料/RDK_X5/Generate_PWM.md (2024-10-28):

现象描述：
我的默认python环境中可以import Hobot.GPIO as GPIO但是这是一个不能直接通过pip安装的包，我在/usr/lib/hobot-gpio/lib/python/Hobot/GPIO/路径下找到了该包

包目录结构：
📦hobot-gpio
 ┣ 📂lib
 ┃ ┗ 📂python
 ┃ ┃ ┣ 📂Hobot
 ┃ ┃ ┃ ┣ 📂GPIO
 ┃ ┃ ┃ ┃ ┣ 📜__init__.py
 ┃ ┃ ┃ ┃ ┣ 📜gpio.py
 ┃ ┃ ┃ ┃ ┣ 📜gpio_event.py
 ┃ ┃ ┃ ┃ ┗ 📜gpio_pin_data.py
 ┃ ┃ ┃ ┗ 📜__init__.py
 ┃ ┃ ┣ 📂Hobot.GPIO.egg-info
 ┃ ┃ ┃ ┣ 📜PKG-INFO
 ┃ ┃ ┃ ┣ 📜SOURCES.txt
 ┃ ┃ ┃ ┣ 📜dependency_links.txt
 ┃ ┃ ┃ ┗ 📜top_level.txt
 ┃ ┃ ┗ 📂RPi
 ┃ ┃ ┃ ┣ 📂GPIO
 ┃ ┃ ┃ ┃ ┗ 📜__init__.py
 ┃ ┃ ┃ ┗ 📜__init__.py
 ┣ 📜LICENCE.txt
 ┣ 📜MANIFEST.in
 ┣ 📜README.md
 ┗ 📜setup.py

我应该如何在我的虚拟环境中(/root/miniforge-pypy3/envs/control/bin/python)导入该包，并且正常驱动pwm

如果需要的化我提供setup.py文件：
```python

from setuptools import setup

classifiers = ['Operating System :: POSIX :: Linux',
               'License :: OSI Approved :: MIT License',
               'Intended Audience :: Developers',
               'Programming Language :: Python :: 2.7',
               'Programming Language :: Python :: 3',
               'Topic :: Software Development',
               'Topic :: System :: Hardware']

setup(name                          = 'Hobot.GPIO',
      version                       = '0.0.2',
      author                        = 'HORIZON',
      author_email                  = 'technical_support@horizon.ai',
      description                   = 'A module to control Hobot GPIO channels',
      long_description              = open('README.md').read(),
      long_description_content_type = 'text/markdown',
      license                       = 'MIT',
      keywords                      = 'Hobot GPIO',
      url                           = '',
      classifiers                   = classifiers,
      package_dir                   = {'': 'lib/python/'},
      packages                      = ['Hobot', 'Hobot.GPIO', 'RPi', 'RPi.GPIO'],
      package_data                  = {'Hobot.GPIO': []},
      include_package_data          = True,
)
```

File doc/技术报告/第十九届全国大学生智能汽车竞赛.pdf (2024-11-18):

# 第十九届全国大学生智能汽车竞赛

# 室外无人驾驶自行车挑战赛

# 技 术 手 册

## 学 校：武汉纺织大学

## 队伍名称：自行车队

## 参赛队员：叶盛廷 袁宏宇 冯睿杰 陈绍鹏 魏

臣阳

## 带队教师：刘丰

## 关于技术手册使用授权的说明

本人完全了解全国大学生智能汽车竞赛关于保留、使用技术手册和研究论 文的规定，即：参赛技术手册内容著作权归参赛者本人，比赛组委会和赞助公 司可以在相关主页上收录并公开参赛作品的设计方案、技术手册、源码以及参 赛模型车的视频、图像资料，并将相关内容编纂收录在组委会出版论文集中。

参赛队员签名：

带队教师签名：
日 | 期： | 2024.11.15

## 第 1章 实验一 视觉处理平台

视觉处理平台的主要任务是为小车提供精准的车道检测与跟踪能力。该平 台架构涵盖了从图像采集到车道线检测、追踪，再到控制输出的一整套系统， 通过硬件加速实现高效能和稳定的实时处理。
视觉处理需要完成的任务主要包括车道检测、目标识别和距离估计等。目 前，计算机视觉领域的处理方法主要分为传统视觉和基于神经网络及深度学习 的视觉技术。其中，基于深度学习和神经网络的视觉平台以其强大的鲁棒性和 准确性在现代自动驾驶领域中脱颖而出，许多厂商纷纷采用这些算法以适应多 变的环境。
本竞赛由于其室外特性，需应对光照强度变化、车道线磨损和阴影遮挡等 问题，因此采用基于神经网络和深度学习的方法显得尤为合适。

1.1 硬件架构设计

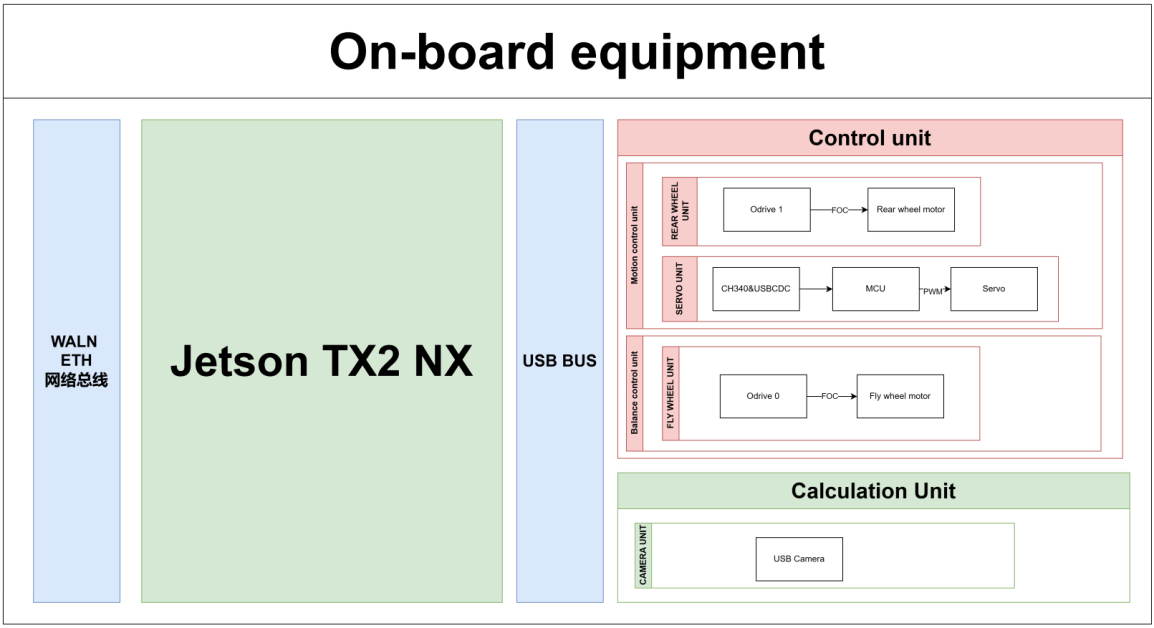
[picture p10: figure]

Figure 1 硬件架构设计

车载设备上我们选用 Jetson TX2 NX 作为主控单元，主要负责视觉平台的计 算和控制单元的运算。摄像头要求不高，具有基础的 RGB 输入和 30FPS 帧率即 可。

操作系统为 Ubuntu 18.04 支持 ROS 和 OpenCV

深度学习框架：Pytorch 和 TensorFlow 用于训练和部署 YOLO 网络

优化工具：基于 Nvidia 的 CUDA 核心调用 TensorRT 对 YOLO 网络进行加 速，提升处理效率和实时性。

1.2 算法架构设计

算法架构流程，对图像进行预处理，使其符合 YOLO 网络的输入，输入 YOLO 网络后 Skeleton 化算法提取车道轮廓，以进一步细化车道主方向，接着对骨架点 进行拟合，最终计算拟合曲线和目标行驶线的水平偏差的代数平均数作为舵机的 输入。

1.3 实验结果分析

1.3.1 YOLO 网络训练结果

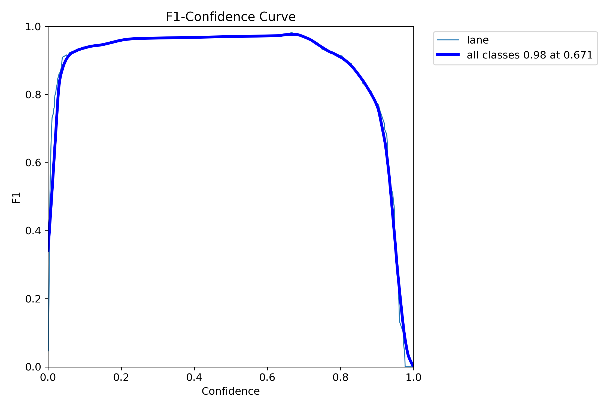
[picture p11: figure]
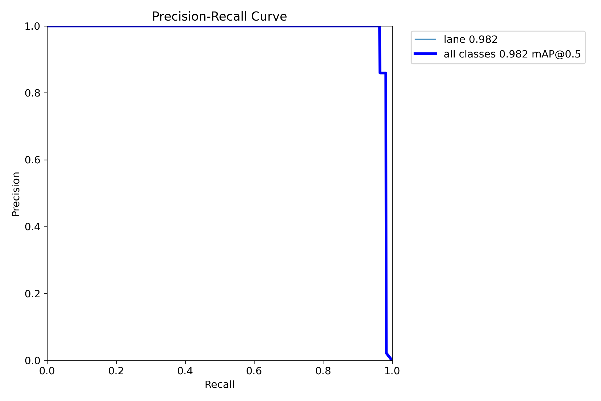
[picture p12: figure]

Figure 2 F1-confidence | Figure 3 PR 测试结果

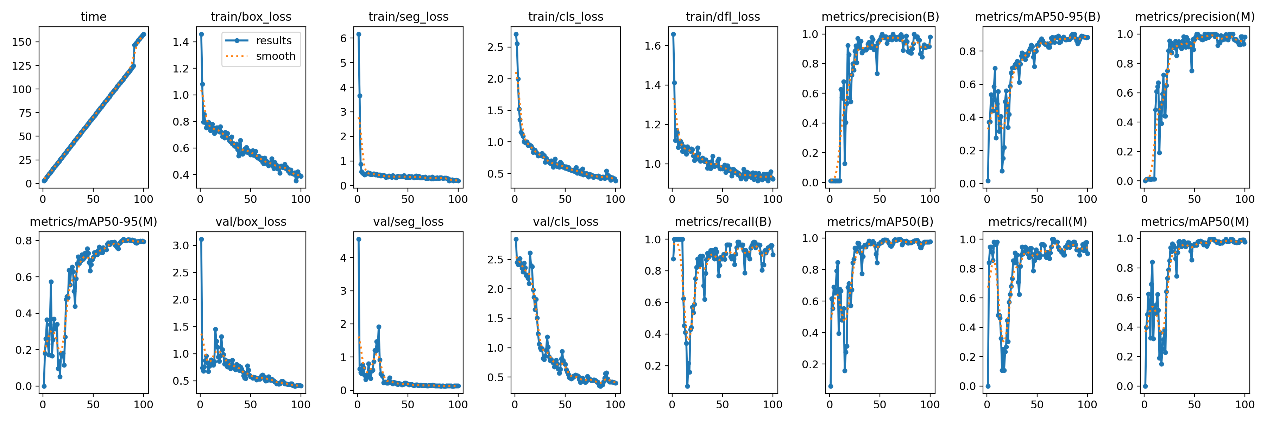
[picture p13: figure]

Figure 4 测试结果

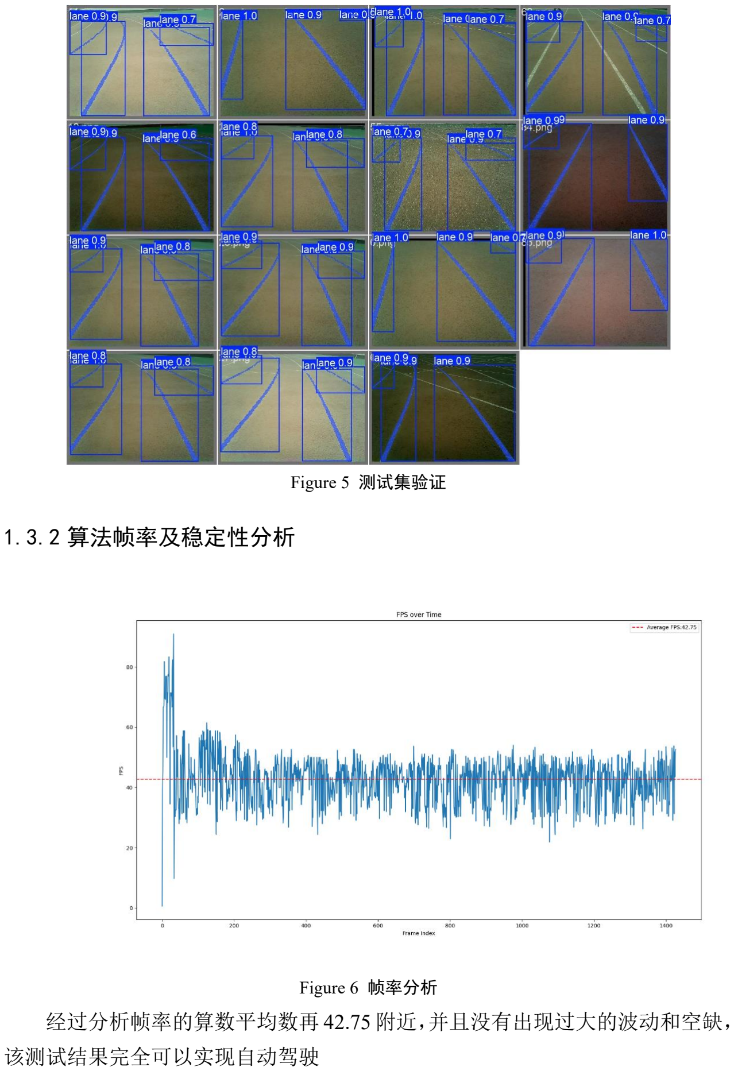
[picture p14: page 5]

Figure 5 测试集验证

1.3.2 算法帧率及稳定性分析

Figure 6 帧率分析
经过分析帧率的算数平均数再 42.75 附近，并且没有出现过大的波动和空缺， 该测试结果完全可以实现自动驾驶

## 第 2章 控制平台设计

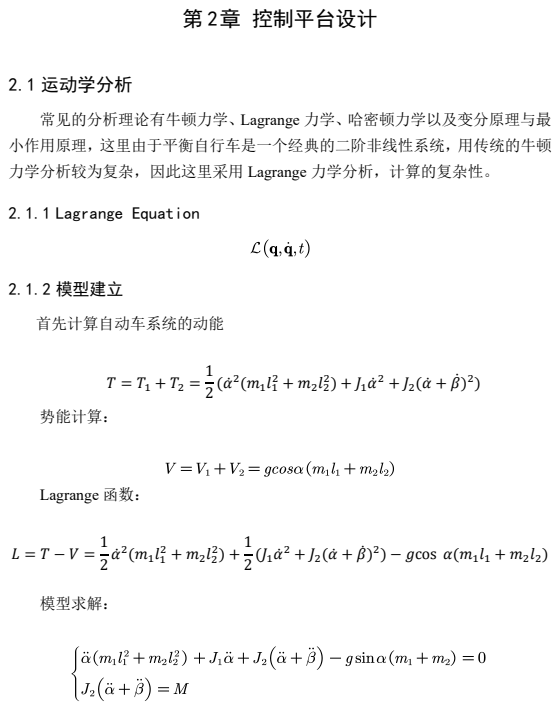
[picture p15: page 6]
2.1 运动学分析; 2.1.1 Lagrange Equation; 2.1.2 模型建立; 首先计算自动车系统的动能; 势能计算：; Lagrange 函数：; ) − gcos α(m1l1 + m2l2); 模型求解：

常见的分析理论有牛顿力学、Lagrange 力学、哈密顿力学以及变分原理与最
小作用原理，这里由于平衡自行车是一个经典的二阶非线性系统，用传统的牛顿
力学分析较为复杂，因此这里采用 Lagrange 力学分析，计算的复杂性。

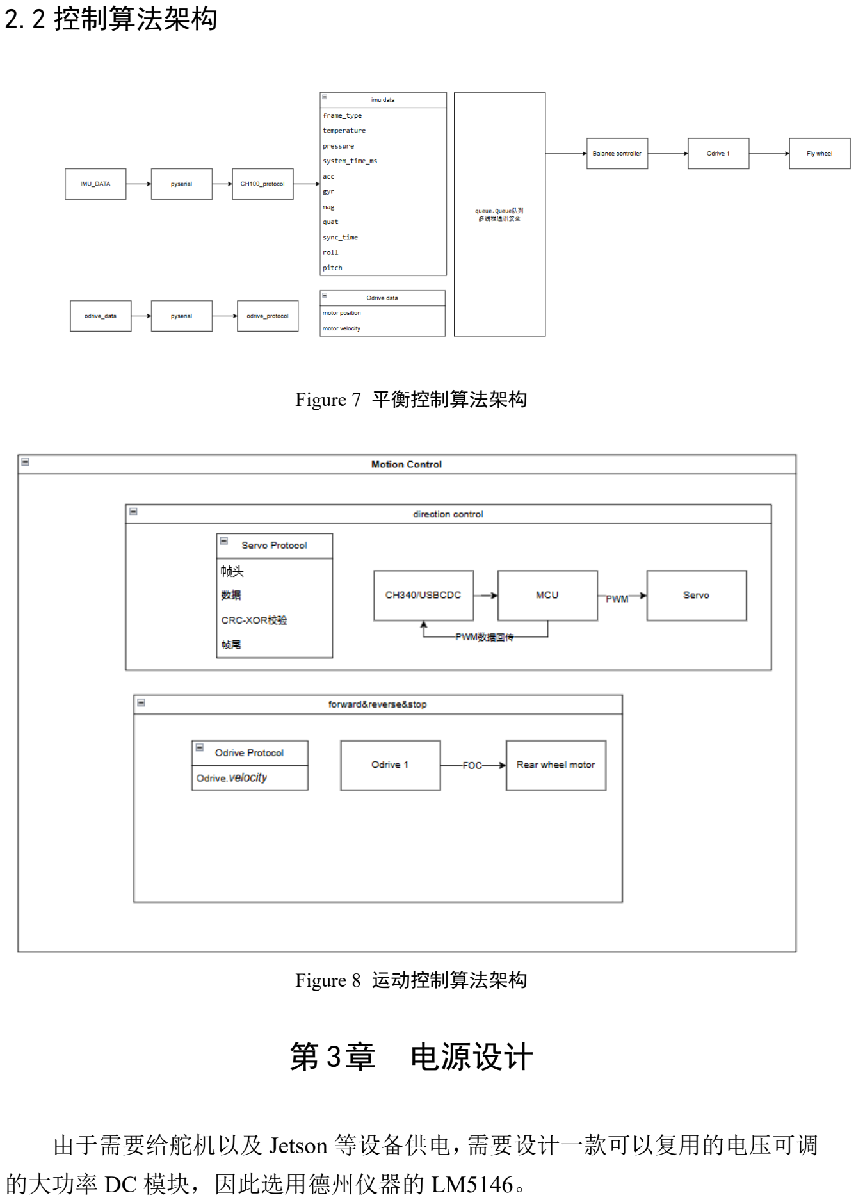
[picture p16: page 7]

2.2 控制算法架构

Figure 7 平衡控制算法架构

Figure 8 运动控制算法架构

## 第 3章 电源设计

由于需要给舵机以及 Jetson 等设备供电，需要设计一款可以复用的电压可调 的大功率 DC 模块，因此选用德州仪器的 LM5146。

3.1 原理图设计

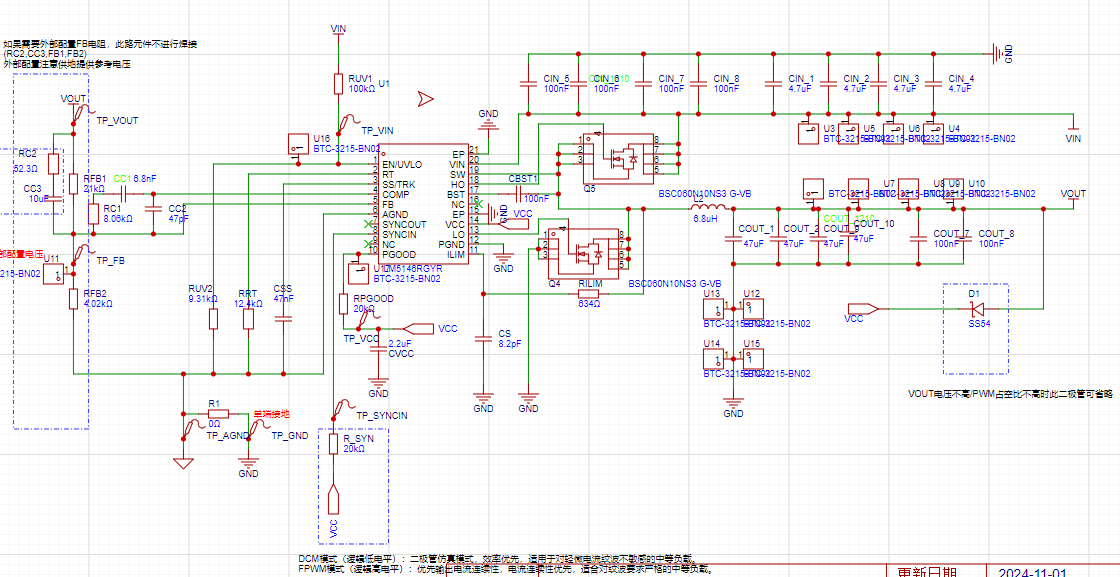
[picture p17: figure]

Figure 9 原理图设计
参考了德州仪器的官方设计文档，并且根据项目需求设定电源接口，参考电 压以及开关频率。

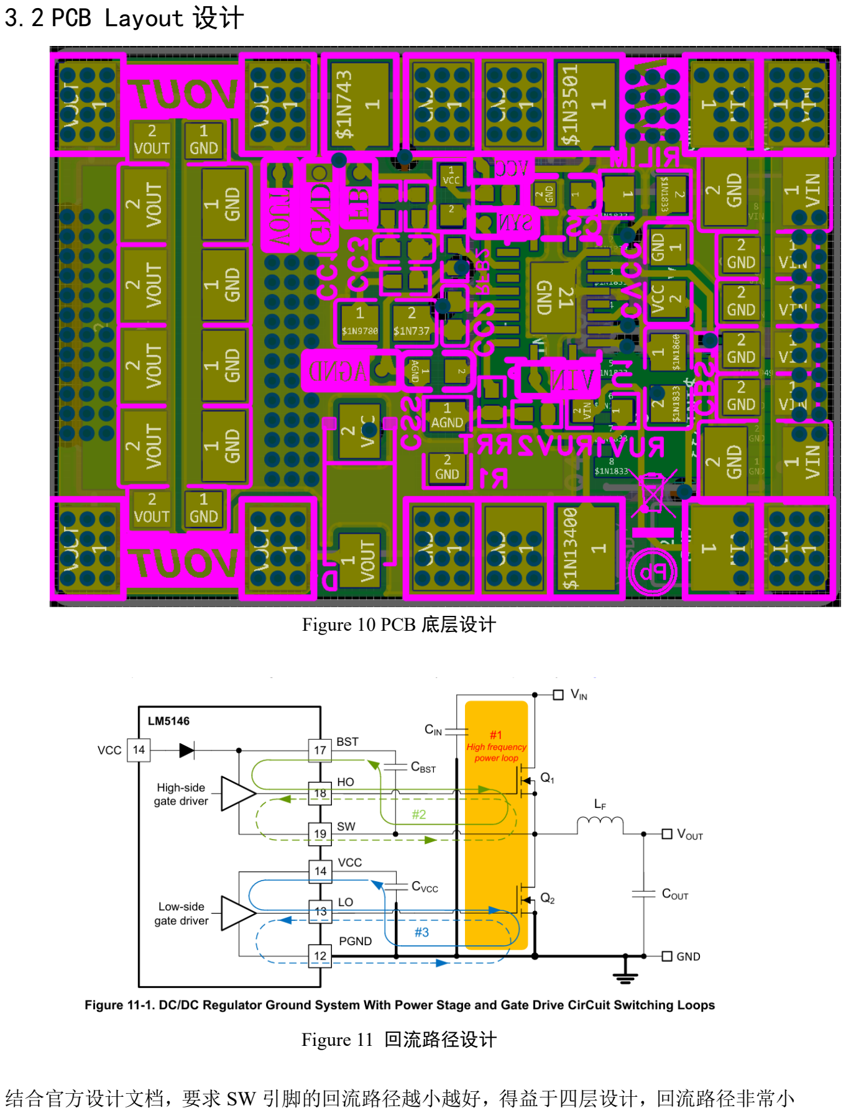
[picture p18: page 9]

3.2 PCB Layout 设计

Figure 10 PCB 底层设计

Figure 11 回流路径设计

结合官方设计文档，要求 SW 引脚的回流路径越小越好，得益于四层设计，回流路径非常小

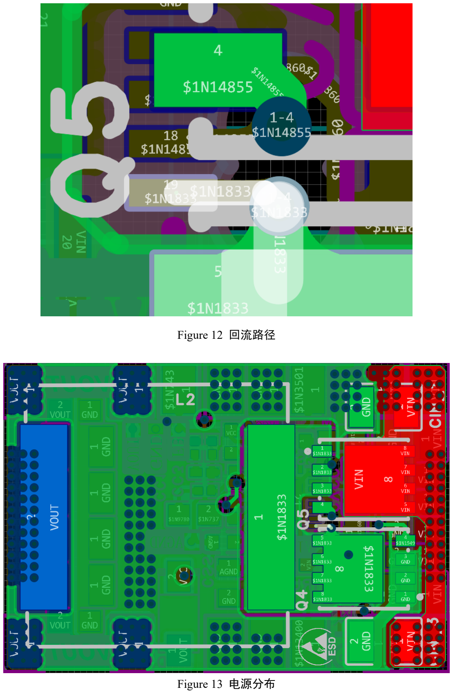
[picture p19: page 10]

Figure 12 回流路径

Figure 13 电源分布

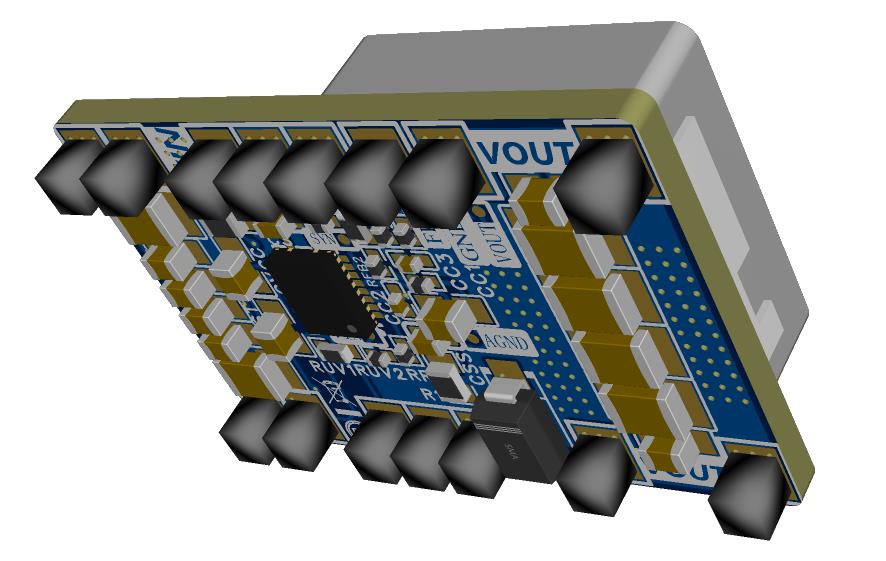
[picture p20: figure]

Figure 14 3D 仿真

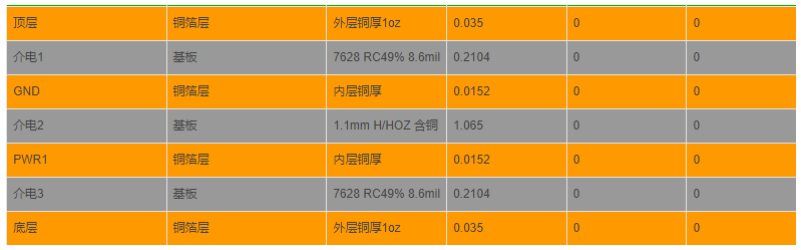
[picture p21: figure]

Figure 15 层堆叠设计

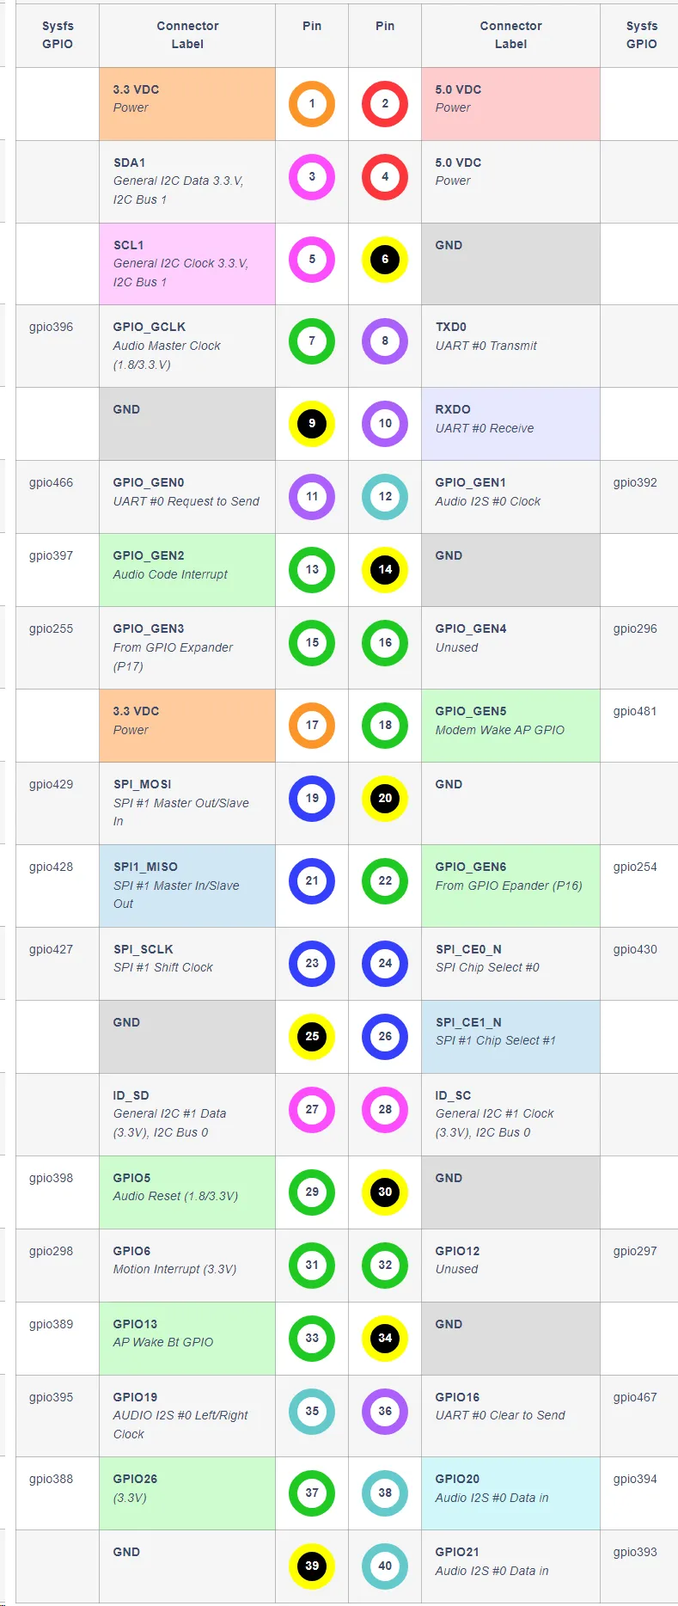
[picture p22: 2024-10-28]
control_unit/doc/jetson/jetson_gpio.png

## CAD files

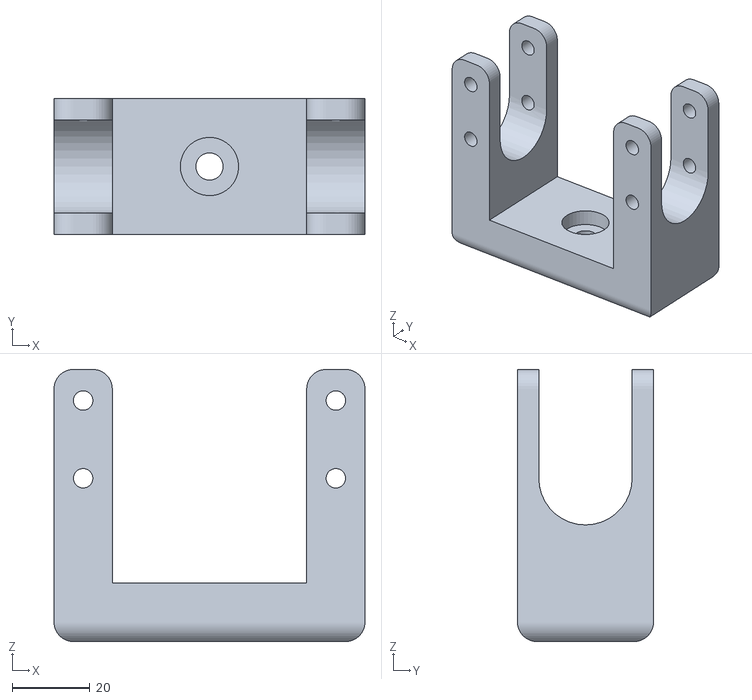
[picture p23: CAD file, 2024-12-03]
struct/打印件/打印件2022/01摄像头部件.STL
80.0 x 35.0 x 70.0

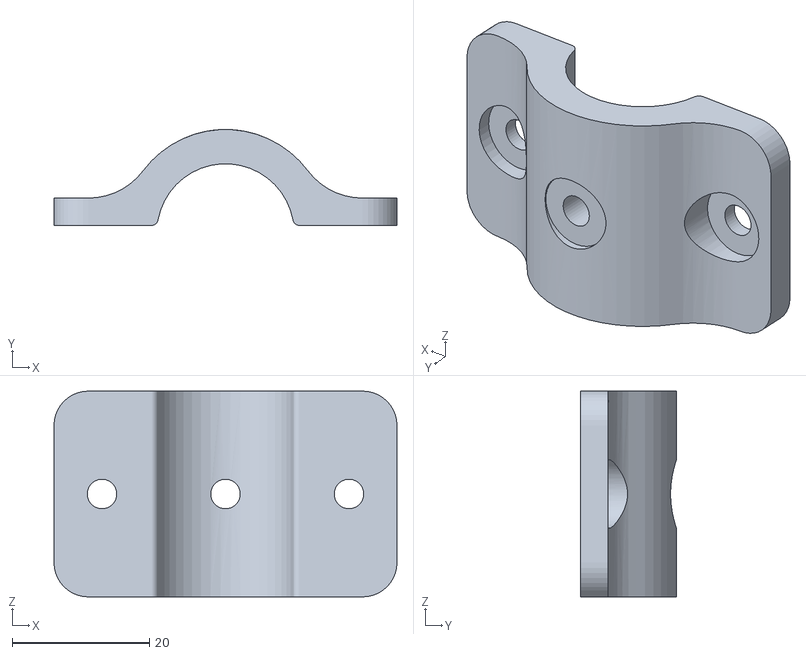
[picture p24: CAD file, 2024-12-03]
struct/打印件/打印件2023/02 舵机/18 车把2.STL
50.0 x 14.0 x 30.0

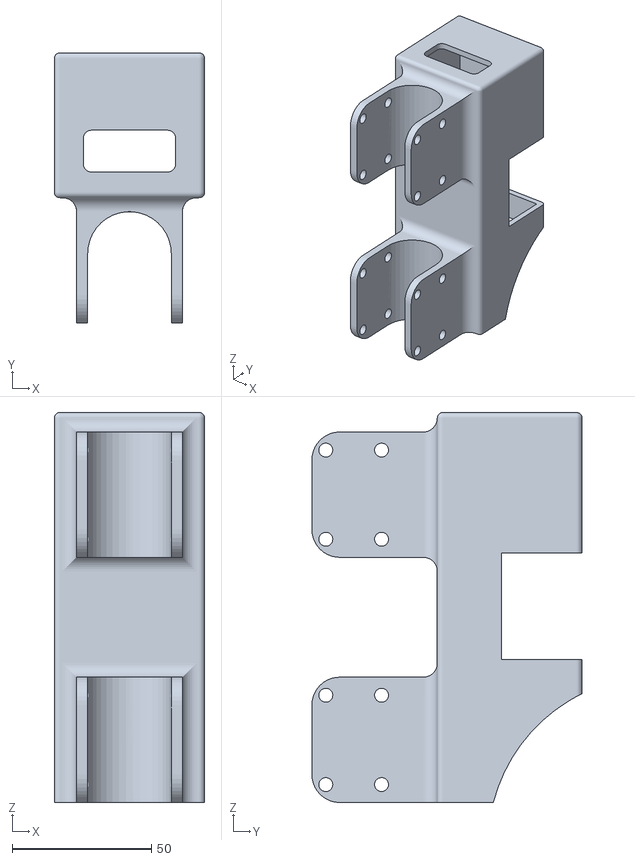
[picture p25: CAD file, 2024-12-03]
struct/打印件/打印件2023/03 电池/03电池支架.STL
54.0 x 97.0 x 140.0

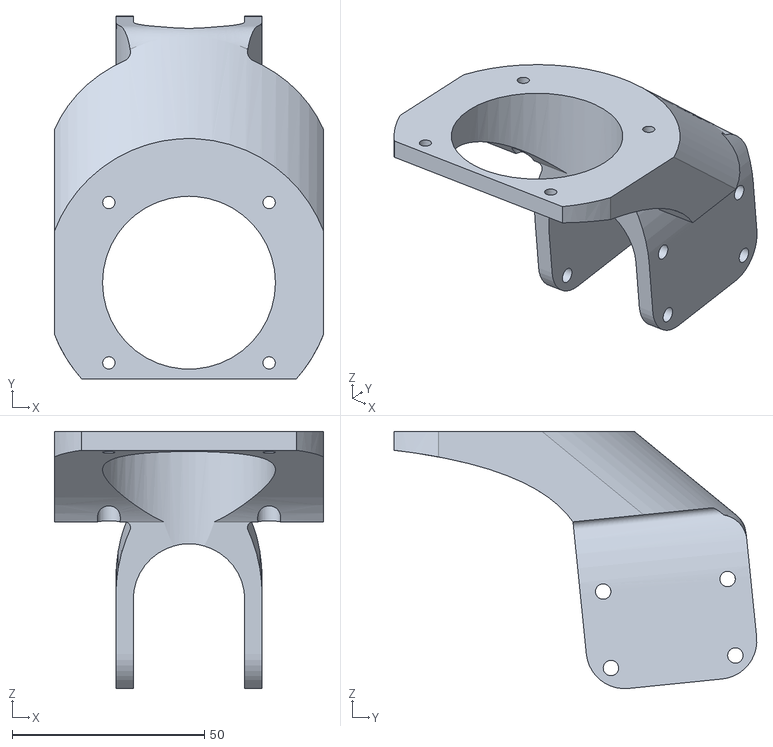
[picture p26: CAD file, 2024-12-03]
struct/打印件/打印件2023/04 激光雷达/04激光雷达支架.STL
70.0 x 94.3 x 66.9

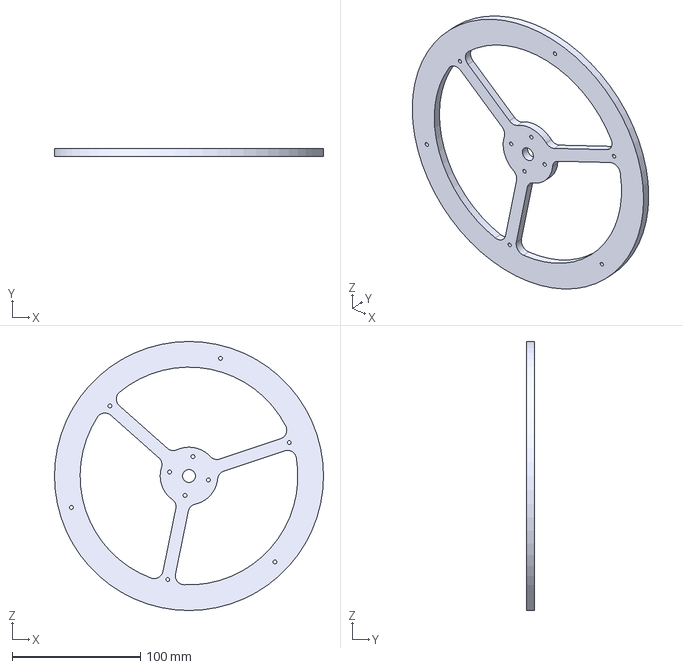
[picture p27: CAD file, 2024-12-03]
struct/打印件/打印件2023/05 动量轮部分/11飞轮.step
210.0 x 6.00 x 210.0 mm

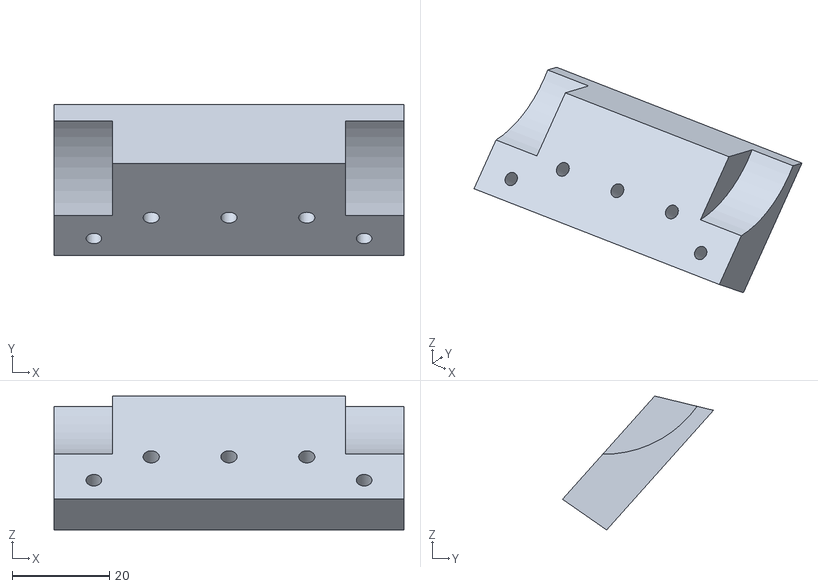
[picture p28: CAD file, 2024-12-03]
struct/打印件/打印件2023/06 后轮驱动部分/11后轮驱动定子22.STL
72.0 x 31.1 x 27.6

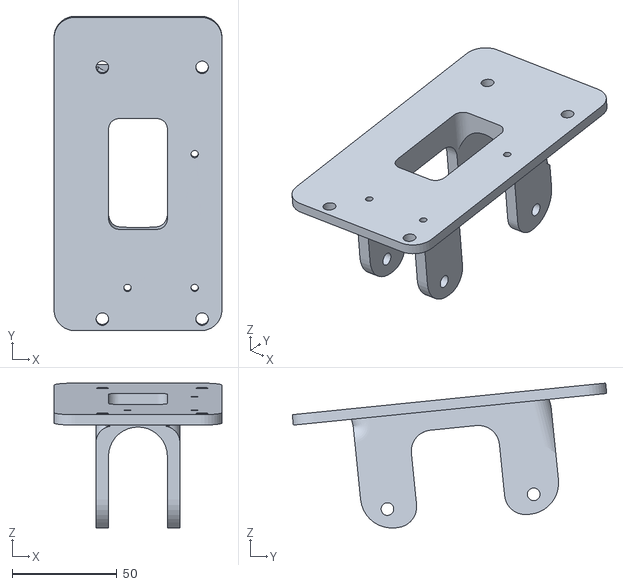
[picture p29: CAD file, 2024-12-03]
struct/打印件/打印件2023/07 硬件设备支撑部分/14 PCB支架.STL
80.0 x 149.7 x 69.0

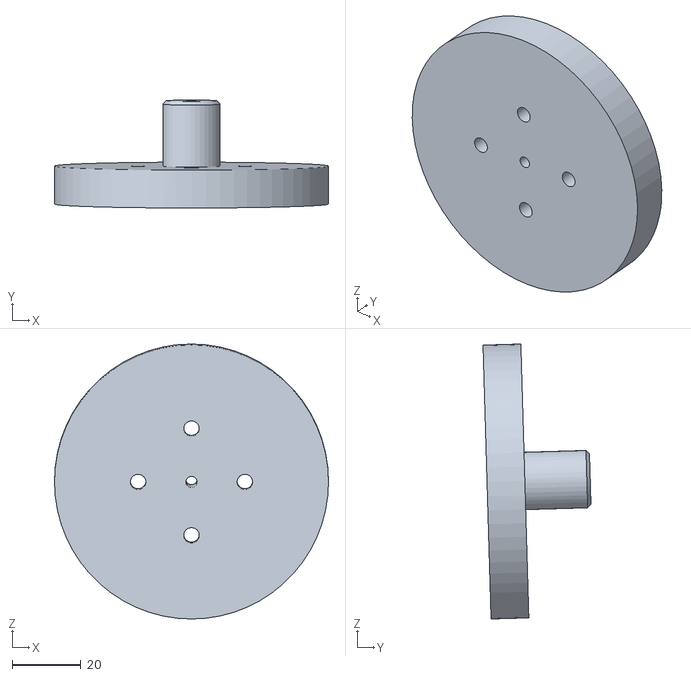
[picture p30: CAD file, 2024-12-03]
struct/打印件/打印件2022/09飞轮垫.STL
79.6 x 31.4 x 79.9

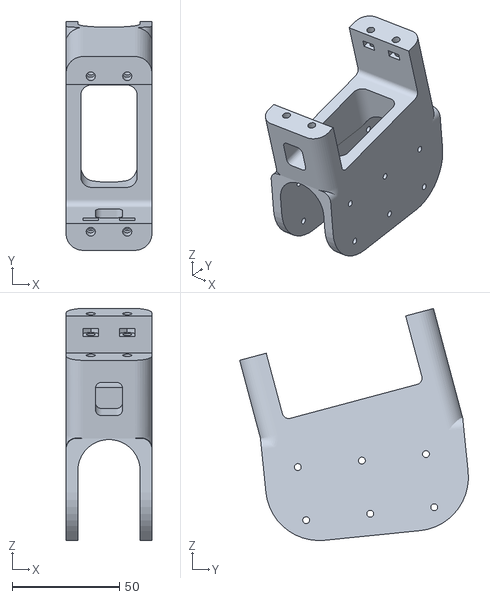
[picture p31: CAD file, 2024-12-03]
struct/打印件/打印件2023/02 舵机/02 舵机支架.STL
40.0 x 106.6 x 108.1

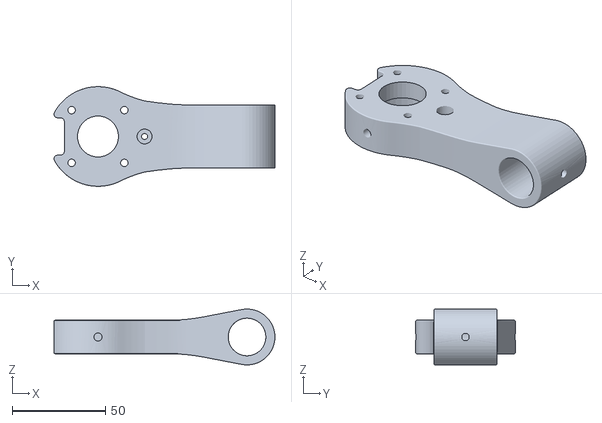
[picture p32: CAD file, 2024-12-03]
struct/打印件/打印件2023/05 动量轮部分/06 动量轮动子.STL
118.6 x 53.5 x 29.9

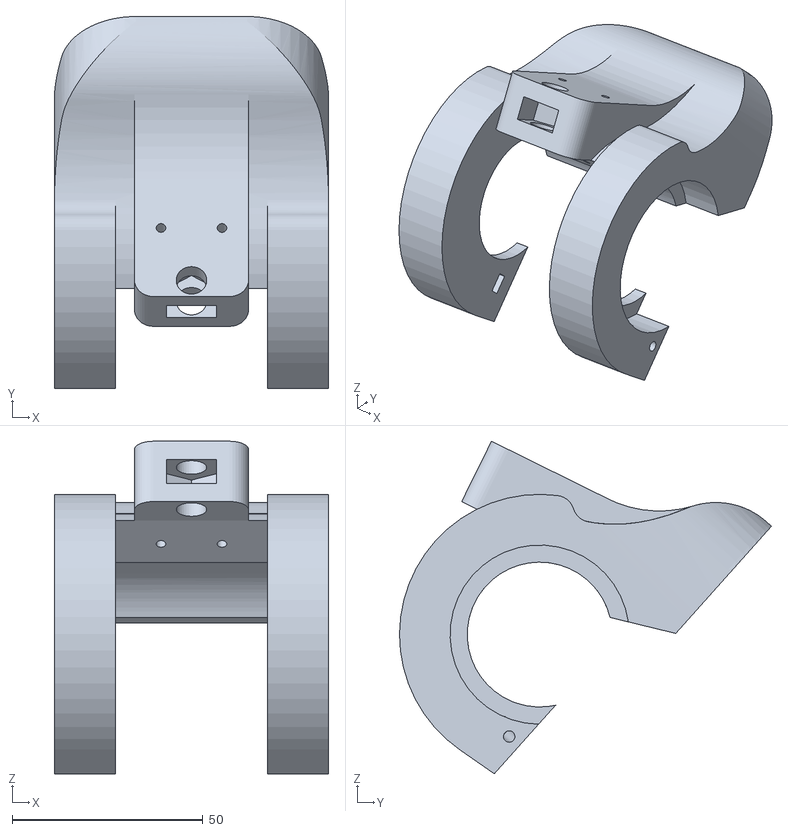
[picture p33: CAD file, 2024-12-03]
struct/打印件/打印件2023/06 后轮驱动部分/10后轮驱动定子11.STL
72.0 x 97.6 x 87.2

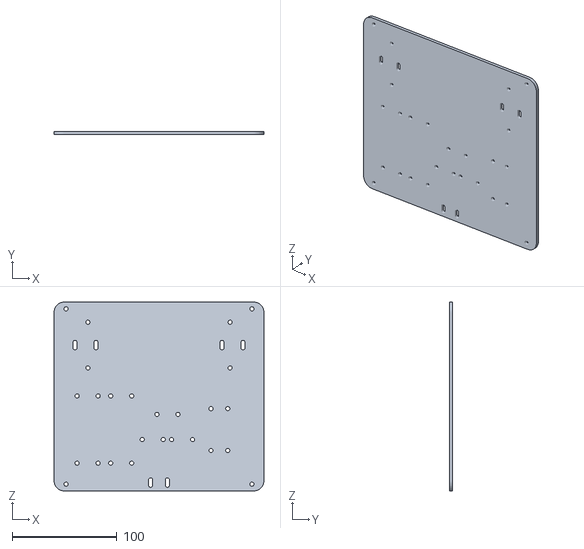
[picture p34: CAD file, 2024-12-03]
struct/打印件/打印件2023/07 硬件设备支撑部分/15 PCB支撑板.STL
200.0 x 3.00 x 180.0

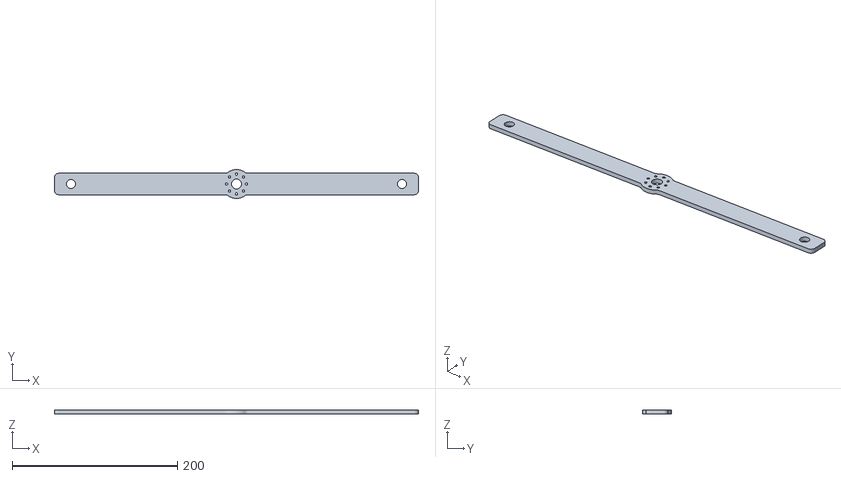
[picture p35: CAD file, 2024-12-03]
struct/打印件/打印件2023/02 舵机/16 支撑臂 无需3D打印.STL
440.0 x 35.0 x 5.00

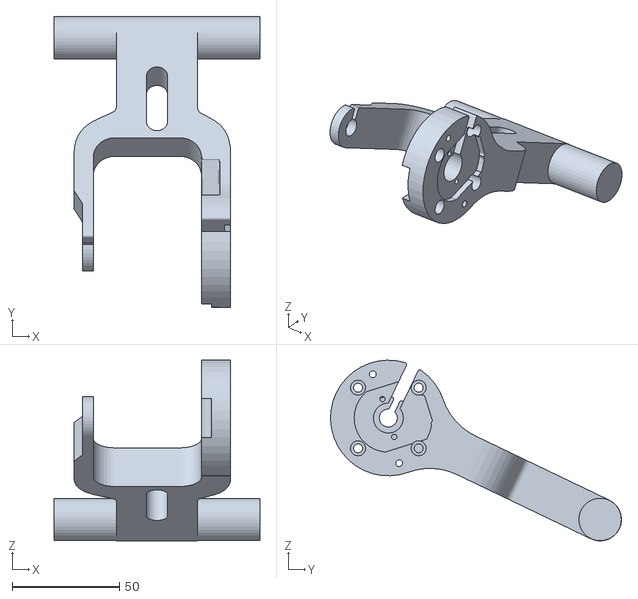
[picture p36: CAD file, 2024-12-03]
struct/打印件/打印件2023/06 后轮驱动部分/12后轮驱动动子.STL
96.0 x 135.8 x 84.3

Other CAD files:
struct/打印件/打印件2022/8活口卡件.STL
struct/打印件/打印件2022/05固定架.STL
struct/打印件/打印件2022/06动量驱动定子_φ6.STL
struct/打印件/打印件2022/07动量驱动动子.stl
struct/打印件/打印件2022/10后轮驱动定子1.STL
struct/打印件/打印件2022/11后轮驱动定子2.STL
struct/打印件/打印件2022/12后轮驱动动子.STL
struct/打印件/打印件2023/02 舵机/17 车把.STL
struct/打印件/打印件2023/05 动量轮部分/05 动量轮定子.STL
struct/打印件/打印件2023/05 动量轮部分/07 转子轴.STL
struct/打印件/打印件2023/05 动量轮部分/08活口卡件1.STL
struct/打印件/打印件2023/05 动量轮部分/10轴套_4个.STL

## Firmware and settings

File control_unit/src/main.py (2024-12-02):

import threading
import time
import json
import logging
import queue
from self_check.self_check import self_check
from ch100_protocol.ch100_protocol import CH100Device
from odrive_protocol.odrive_protocol import ODriveAsciiProtocol
from balance_control.balance_control import control_layer  # 导入 control_layer 函数
from directional_control.directional_control import (
    DirectionalControl,
)  # 导入 DirectionalControl 类
import socket
import serial

from balance_control.balance_control import process_speedBack_message  # 导入 process_speedBack_message 中的函数
from balance_control.balance_control import process_steer_dynamicAngle
# 移除所有的日志处理程序，关闭日志模块
logging.getLogger().handlers.clear()


# 加载配置
def load_config(file_path="/home/jetson/workspace/EquiCycle/control_unit/src/config.json"):
    with open(file_path, "r") as f:
        return json.load(f)


config = load_config()

# 设备配置
ch100_config = config["ch100"]
odrive_config = config["odrive"]
servo_config = config["servo"]

# 初始化串口
ser = serial.Serial(servo_config["port"], servo_config["baudrate"])

# 全局停止事件
stop_event = threading.Event()

# 用于线程间通信的队列
data_queue = queue.Queue()

# 创建 DirectionalControl 实例
directional_control = DirectionalControl()


def ch100_thread_function(data_queue):
    """
    CH100 线程从 CH100 串口设备读取数据并将其放入队列中。
    """
    logging.info("启动 CH100 线程")
    ch100_device = CH100Device(
        port=ch100_config["port"], baudrate=ch100_config["baudrate"]
    )
    ch100_device.open()

    try:
        while not stop_event.is_set():
            frames = ch100_device.read_and_parse()
            for frame in frames:
                frame["device"] = "ch100"  # 添加设备标识符
                data_queue.put(frame)  # 将帧放入队列
                logging.debug(f"已将 CH100 帧添加到队列: {frame}")
    except Exception as e:
        logging.error(f"CH100 线程错误: {e}")
    finally:
        ch100_device.close()
        logging.info("CH100 线程已停止")


def odrive_thread_function(odrive_instance, data_queue):
    """
    ODrive 线程从 ODrive 电机控制器读取反馈并将其放入队列中。
    """
    logging.info("启动 ODrive 线程")

    try:
        while not stop_event.is_set():
            try:
                feedback = odrive_instance.request_feedback(0)
                data = {
                    "device": "odrive",  # 添加设备标识符
                    "feedback": feedback,
                }
                data_queue.put(data)  # 将反馈放入队列
            except Exception as e:
                logging.error(f"ODrive 线程错误: {e}")
            time.sleep(0.005)  # 限制请求速率为 5ms
    finally:
        odrive_instance.close()
        logging.info("ODrive 线程已停止")


def control_thread_function(odrive_instance, data_queue):
    """
    控制线程从队列中读取数据并将其传递给控制层进行处理。
    """
    logging.info("启动控制线程")

    try:
        while not stop_event.is_set():
            try:
                data = data_queue.get(timeout=1)
                control_layer(data, odrive_instance)  # 将数据传递给控制层
            except queue.Empty:
                pass  # 超时发生，继续循环
            except Exception as e:
                logging.error(f"控制线程错误: {e}")
    finally:
        logging.info("控制线程已停止")


def servo_listener():
    """
    UDP 监听线程，用于接收数据并解析脉冲值
    """
    with socket.socket(socket.AF_INET, socket.SOCK_DGRAM) as sock:
        sock.bind((servo_config["udp_host"], servo_config["udp_port"]))
        print("从机端已启动，等待主机端数据...")

        while not stop_event.is_set():
            data, addr = sock.recvfrom(1024)
            if data:
                # 解析数据协议并更新脉冲值
                pulse_value = directional_control.parse_protocol(data)
                if pulse_value is not None:
                    # 将数据转发到串口
                    ser.write(data)
                    process_steer_dynamicAngle(pulse_value)
                    print("接收到的数据帧:", [hex(x) for x in data])
                    
def speed_BackWheel_listener():
    """
    新增的UDP监听线程，用于接收来自另一个端口的指令
    """
    with socket.socket(socket.AF_INET, socket.SOCK_DGRAM) as sock:
        sock.bind(("0.0.0.0", 12345))  # 监听端口 12345
        print("视觉监听线程已启动，等待控制指令...")

        while not stop_event.is_set():
            data, addr = sock.recvfrom(1024)
            if data:
                # 假设收到的数据格式是 "v <target> <speed>"
                control_message = data.decode("utf-8").strip()
                print(f"接收到视觉的控制指令: {control_message}")

                # 调用 balance_control 中的函数来处理控制消息
                try:
                    process_speedBack_message(control_message)
                except Exception as e:
                    logging.error(f"处理控制指令时发生错误: {e}")
            else:
                process_speedBack_message(0)

def main():
    # 在启动线程之前执行系统自检
    self_check("ch100", "odrive")

    # 初始化 ODrive 实例
    odrive_instance = ODriveAsciiProtocol(
        port=odrive_config["port"], baudrate=odrive_config["baudrate"]
    )

    # 创建线程
    threads = [
        threading.Thread(
            target=ch100_thread_function, args=(data_queue,), name="CH100Thread"
        ),
        threading.Thread(
            target=odrive_thread_function,
            args=(odrive_instance, data_queue),
            name="ODriveThread",
        ),
        threading.Thread(
            target=control_thread_function,
            args=(odrive_instance, data_queue),
            name="ControlThread",
        ),
        threading.Thread(
            target=servo_listener, name="ServoListener"
        ),  # 新增的 servo_listener 线程
        threading.Thread(
            target=speed_BackWheel_listener,
            name="SpeedBackWheelListener",
        ),
    ]

    # 启动所有线程
    for thread in threads:
        thread.start()

    try:
        while True:
            time.sleep(1)
    except KeyboardInterrupt:
        logging.info("主线程被用户中断")
        stop_event.set()
    finally:
        # 等待所有线程完成
        for thread in threads:
            thread.join()
        logging.info("所有线程已停止")


if __name__ == "__main__":
    main()

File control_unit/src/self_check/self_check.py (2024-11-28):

import logging
import sys
import serial
import json
import psutil  # 用于检测和终止进程

# 配置日志
logging.basicConfig(
    level=logging.INFO, format="%(asctime)s - %(levelname)s - %(message)s"
)


# 从 JSON 文件读取设备配置
def load_device_config(filename="/home/jetson/workspace/EquiCycle/control_unit/src/config.json"):
    with open(filename, "r") as f:
        return json.load(f)


# 检查端口是否被占用
def is_port_in_use(port):
    """检查端口是否被占用"""
    for conn in psutil.net_connections():
        if conn.laddr.port == port:
            return True
    return False


# 释放占用端口的进程
def release_port(port):
    """释放占用端口的进程"""
    for proc in psutil.process_iter(["pid", "name"]):
        # 过滤掉系统进程
        if proc.info["pid"] == 0:
            continue
        for conn in proc.connections(kind="inet"):
            if conn.laddr.port == port:
                logging.info(
                    f"正在终止占用端口 {port} 的进程 {proc.info['name']} (PID: {proc.info['pid']})"
                )
                try:
                    proc.terminate()
                    proc.wait(timeout=3)  # 等待进程终止
                except (psutil.NoSuchProcess, psutil.AccessDenied):
                    logging.error(
                        f"无法终止进程 {proc.info['name']} (PID: {proc.info['pid']})"
                    )
                return True
    return False


# 端口检测与释放
def check_and_release_ports(port_list):
    for port in port_list:
        if is_port_in_use(port):
            logging.warning(f"端口 {port} 已被占用，尝试释放...")
            if release_port(port):
                logging.info(f"端口 {port} 已成功释放")
            else:
                logging.error(f"端口 {port} 无法释放，请手动检查")
                sys.exit(1)
        else:
            logging.info(f"端口 {port} 可用")


# 设备自检
def self_check(*device_names):
    # 读取设备配置
    device_config = load_device_config()

    # 检查指定的设备端口是否正常
    zmq_ports = []
    for device_name in device_names:
        if device_name not in device_config:
            logging.error(f"未知设备名称: {device_name}")
            sys.exit(1)

        port = device_config[device_name]["port"]
        baudrate = device_config[device_name]["baudrate"]
        zmq_ports.append(device_config[device_name]["zmq_port"])  # 收集 ZMQ 端口

        try:
            # 检查设备端口
            with serial.Serial(port=port, baudrate=baudrate, timeout=1) as ser:
                logging.info(
                    f"{device_name.upper()} 自检通过: 端口连接正常，波特率正常"
                )

        except serial.SerialException as e:
            logging.error(f"{device_name.upper()} 自检失败: {e}")
            sys.exit(1)

    # 检查 ZMQ 端口是否被占用
    check_and_release_ports(zmq_ports)


# 示例调用
if __name__ == "__main__":
    self_check("ch100", "odrive")  # 同时检查 ch100 和 odrive

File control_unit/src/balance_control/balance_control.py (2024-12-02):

import threading
import logging
import time

# Initialize shared control parameters and lock
control_params = {}
control_params_lock = threading.Lock()

# Global variables for PID control
previous_error = 0.0
integral = 0.0
last_time = time.time()

flag_Crossing_1 = 0
flag_Crossing_2 = 0
flag_Crossing_over = 0
count_Crossing_2 = 0

stop_count = 0          # 直立计数变量
flag_go = 0             # 直立元素完成标志

MOTOR_SPEED_LIMIT = 25  # 速度限幅


class PIDController:
    def __init__(self, kp, ki, kd, limit, setpoint=0, output_limits=(None, None)):
        self.kp = kp
        self.ki = ki
        self.kd = kd
        self.setpoint = setpoint
        self.integral = 0
        self.previous_error = 0
        self.output_limits = output_limits
        self.last_value = 0
        self.limit  = limit

    def update(self, feedback_value):
        feedback_value = 0.5 * self.last_value + 0.5 * feedback_value
        error = self.setpoint - feedback_value
        self.integral += error
        if self.integral > self.limit:
          self.integral = self.limit
        elif self.integral < -self.limit:
          self.integral = -self.limit
        derivative = (error - self.previous_error)
        output = self.kp * error + self.ki * self.integral + self.kd * derivative
        
        if self.output_limits[0] is not None:
            output = max(self.output_limits[0], output)
        if self.output_limits[1] is not None:
            output = min(self.output_limits[1], output)
        
        self.previous_error = error
        self.last_value = feedback_value
        return output



# self.gyro_pid = PIDController(kp=2.3, ki=0, kd=0.001, output_limits=(-MOTOR_SPEED_LIMIT, MOTOR_SPEED_LIMIT))
 # self.angle_pid = PIDController(kp=5.2, ki=0, kd=3.8, output_limits=(-MOTOR_SPEED_LIMIT, MOTOR_SPEED_LIMIT))
# self.velocity_pid = PIDController(kp=-0.088, ki=-0.0003, kd=-0, output_limits=(-MOTOR_SPEED_LIMIT, MOTOR_SPEED_LIMIT))


#  self.gyro_pid = PIDController(kp=2.7, ki=0, kd=0.001,limit = 0, output_limits=(-MOTOR_SPEED_LIMIT, MOTOR_SPEED_LIMIT))
#      self.angle_pid = PIDController(kp=4.8, ki=0.00001, kd=2.7,limit = 10000, output_limits=(-MOTOR_SPEED_LIMIT, MOTOR_SPEED_LIMIT))
 #       self.velocity_pid = PIDController(kp=-0.093, ki=-0.0003, kd=-0,limit = 10000, output_limits=(-MOTOR_SPEED_LIMIT, MOTOR_SPEED_LIMIT))

# offset_angle = 1.7 + (parameters['pulse_value'] - 978)
offset_angle = 2.05     # 左右零点
factor_dynamic_steer = 0.0067
v_basic = -3              # 直立之后后轮速度
Stand_time = 50000000       # 直立时间 2250 -> 30s
class CascadedPIDController:
    def __init__(self):
        self.gyro_pid = PIDController(kp=3.7, ki=0, kd=0.07,limit = 0, output_limits=(-MOTOR_SPEED_LIMIT, MOTOR_SPEED_LIMIT))
        self.angle_pid = PIDController(kp=3.5, ki=0.00001, kd=3,limit = 10000, output_limits=(-MOTOR_SPEED_LIMIT, MOTOR_SPEED_LIMIT))
        self.velocity_pid = PIDController(kp=-0.12, ki=-0.0009, kd=-0.03,limit = 10000, output_limits=(-MOTOR_SPEED_LIMIT, MOTOR_SPEED_LIMIT))
        # self.velocity_pid = PIDController(kp=-0, ki=-0, kd=-0,limit = 10000, output_limits=(-MOTOR_SPEED_LIMIT, MOTOR_SPEED_LIMIT))
       
        #self.gyro_pid = PIDController(kp=3.13, ki=0, kd=0.07,limit = 0, output_limits=(-MOTOR_SPEED_LIMIT, MOTOR_SPEED_LIMIT))
        #self.angle_pid = PIDController(kp=3.7, ki=0.000007, kd=3,limit = 10000, output_limits=(-MOTOR_SPEED_LIMIT, MOTOR_SPEED_LIMIT))
        #self.velocity_pid = PIDController(kp=-0.12, ki=-0.0009, kd=-0.03,limit = 10000, output_limits=(-MOTOR_SPEED_LIMIT, MOTOR_SPEED_LIMIT))0.75

        # self.gyro_pid = PIDController(kp=3.0, ki=0, kd=0,limit = 0, output_limits=(-MOTOR_SPEED_LIMIT, MOTOR_SPEED_LIMIT))
        # self.angle_pid = PIDController(kp=4.5, ki=0.000017, kd=2.8,limit = 10000, output_limits=(-MOTOR_SPEED_LIMIT, MOTOR_SPEED_LIMIT))
        # self.velocity_pid = PIDController(kp=-0.095, ki=-0.00117, kd=-0.015,limit = 10000, output_limits=(-MOTOR_SPEED_LIMIT, MOTOR_SPEED_LIMIT))

        self.gyro_update_counter = 0
        self.angle_control_signal = 0
        self.velocity_control_signal = 0

    def update(self, current_angular_velocity, current_angle, current_velocity):
        if self.gyro_update_counter % 4 == 0:
            self.velocity_pid.setpoint = 0.0
            self.velocity_control_signal = self.velocity_pid.update(current_velocity)

        if self.gyro_update_counter % 2 == 0:
            self.angle_pid.setpoint = self.velocity_control_signal
            self.angle_control_signal = self.angle_pid.update(current_angle - offset_angle)

        self.gyro_pid.setpoint = self.angle_control_signal
        control_signal = self.gyro_pid.update(current_angular_velocity)

        if (current_angle - offset_angle) < -8 or (current_angle - offset_angle) > 8:
            control_signal = 0

        if self.gyro_update_counter == 4:
            self.gyro_update_counter = 0
        self.gyro_update_counter += 1

        return control_signal


def control_layer(data, odrive_instance):
    device = data.get("device")

    if device == "ch100":
        process_ch100_data(data)
    elif device == "odrive":
        process_odrive_data(data)
        adjust_motor_speed(odrive_instance, CascadePIDclass)
    else:
        logging.warning(f"Unknown device data: {data}")


def process_ch100_data(data):
    roll = data.get("roll", 0.0)
    pitch = data.get("pitch", 0.0)
    yaw = data.get("yaw", 0.0)
    euler_angles = {"roll": roll, "pitch": pitch, "yaw": yaw}

    angular_velocity = data.get("gyr", [0.0, 0.0, 0.0])
    gyro_data = {"x": angular_velocity[0], "y": angular_velocity[1], "z": angular_velocity[2]}

    with control_params_lock:
        control_params["euler_angles"] = euler_angles
        control_params["gyro"] = gyro_data


def process_odrive_data(data):
    feedback = data.get("feedback", "")
    if feedback:
        feedback_values = feedback.split()
        motor_position = float(feedback_values[0])
        motor_speed = float(feedback_values[1])

    with control_params_lock:
        control_params["motor_position"] = motor_position
        control_params["motor_speed"] = motor_speed

v_vision = None
def process_speedBack_message(message):
    # 解析并处理控制消息
    global v_vision
    parts = message.split()
    if len(parts) == 3 and parts[0] == 'v' and parts[1] == '1':
        v_vision = float(parts[2])
        
        # 你可以在这里添加更多的逻辑来处理控制指令
    else:
        v_vision = None

dynamic_angle_steer = 0.0
def process_steer_dynamicAngle(message):
    # 解析并处理控制消息
    global dynamic_angle_steer,factor_dynamic_steer
    
    if message <830:
        message = 830
    elif message > 1130:
        message = 1130
    # message = message < 830 ? 830 : ( message > 1130 ? 1130 : message )
    dynamic_angle_steer = factor_dynamic_steer * (message-978)
                
CascadePIDclass = CascadedPIDController()
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

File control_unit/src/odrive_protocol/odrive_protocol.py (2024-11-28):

import serial
import serial.tools.list_ports


class ODriveAsciiProtocol:
    def __init__(self, port: str, baudrate: int = 460800):
        self.serial = serial.Serial(port, baudrate, timeout=1)

    def send_command(self, command: str):
        # Debug information: Show the command being sent
        # print(f"Sending command: {command}")
        # Send command to the ODrive, with newline character
        self.serial.write(f"{command}\n".encode())

    def read_response(self):
        # Read the response from ODrive
        response = self.serial.readline().decode().strip()
        # Debug information: Show the response received
        print(f"Received response: {response}")
        return response

    def motor_trajectory(self, motor: int, destination: float):
        command = f"t {motor} {destination}"
        self.send_command(command)

    def motor_position(
        self,
        motor: int,
        position: float,
        velocity_lim: float = None,
        torque_lim: float = None,
    ):
        command = f"q {motor} {position}"
        if velocity_lim is not None:
            command += f" {velocity_lim}"
        if torque_lim is not None:
            command += f" {torque_lim}"
        self.send_command(command)

    def motor_position_stream(
        self,
        motor: int,
        position: float,
        velocity_ff: float = 0.0,
        torque_ff: float = 0.0,
    ):
        command = f"p {motor} {position} {velocity_ff} {torque_ff}"
        self.send_command(command)

    def motor_velocity(self, motor: int, velocity: float, torque_ff: float = 0.0):
        command = f"v {motor} {velocity}"
        self.send_command(command)

    def motor_current(self, motor: int, torque: float):
        command = f"c {motor} {torque}"
        self.send_command(command)

    def request_feedback(self, motor: int):
        command = f"f {motor}"
        self.send_command(command)
        return self.read_response()

    def update_watchdog(self, motor: int):
        command = f"u {motor}"
        self.send_command(command)

    def read_parameter(self, property_name: str):
        command = f"r {property_name}"
        self.send_command(command)
        return self.read_response()

    def write_parameter(self, property_name: str, value: float):
        command = f"w {property_name} {value}"
        self.send_command(command)

    def system_command(self, command_type: str):
        valid_commands = {"ss", "se", "sr", "sc"}
        if command_type not in valid_commands:
            raise ValueError(f"Invalid system command: {command_type}")
        self.send_command(command_type)

    def check_info(self):
        # 发送一系列指令以获取 ODrive 的状态和参数
        print("请求 ODrive 设备的所有信息...")
        responses = {}

        # 查询固件版本
        responses["firmware_version"] = self.read_parameter("fw_version")
        # 查询电源电压
        responses["vbus_voltage"] = self.read_parameter("vbus_voltage")
        # 查询轴状态
        responses["axis0_state"] = self.request_feedback(0)
        responses["axis1_state"] = self.request_feedback(1)

        # 可以根据需要添加更多的查询指令
        # 例如：查询轴的错误状态
        responses["axis0_error"] = self.read_parameter("axis0.error")
        responses["axis1_error"] = self.read_parameter("axis1.error")

        print("获取的信息:", responses)
        return responses

    def close(self):
        self.serial.close()

    @staticmethod
    def find_odrive():
        # 常见的波特率列表，按常见性排序
        common_baudrates = [115200, 9600, 230400, 57600, 500000, 1000000]

        # 列出所有可用的串口
        available_ports = list(serial.tools.list_ports.comports())
        print("正在扫描可用的串口...")

        # 尝试每个串口和波特率
        for port_info in available_ports:
            port = port_info.device
            print(f"尝试连接端口: {port}")
            for baudrate in common_baudrates:
                print(f"尝试波特率: {baudrate}")
                try:
                    # 打开串口
                    ser = serial.Serial(port, baudrate, timeout=1)
                    ser.write(b"r vbus_voltage\n")  # 发送简单的命令，检查是否有响应
                    response = ser.readline().decode().strip()
                    if response:  # 如果有响应，说明可能是 ODrive 设备
                        print(f"找到 ODrive 设备, 端口: {port}, 波特率: {baudrate}")
                        ser.close()
                        return ODriveAsciiProtocol(port, baudrate)
                    ser.close()
                except (serial.SerialException, OSError) as e:
                    # 如果尝试失败，继续尝试下一个组合
                    print(f"连接失败: {e}")

        print("未找到 ODrive 设备。")
        return None

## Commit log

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2024-04-07 增加板框dxf文件
    [供电板板框.DXF]
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2024-05-03 增加gitnore，忽略生成的中间文件
    [供电板板框.DXF]
2024-05-05 增加IMU API的测试版本
    [一帧数据.csv]
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2024-07-22 feat USART1): 添加USART1支持及中断处理
    - 在CMakeLists.txt中添加了USART1相关的源文件和头文件路径。
    - 在main.h中包含了wit_imu.h头文件。
    - 在stm32h7xx_it.h中添加了USART1_IRQHandler函数的声明。
    - 在usart.h中添加了UART_HandleTypeDef huart1的声明。
    - 在usart.c中添加了关于USART1的初始化和配置代码。
    - 同时更新了equicycle.ioc文件，添加了USART1的相关配置。
    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
2024-07-22 feat(USART1): 添加USART1支持及中断处理
    - 在main.h中包含了string.h和wit_imu.h头文件。
    - 在stm32h7xx_it.c中实现了USART1_IRQHandler中断处理函数。
    - 在usart.c中添加了关于USART1的初始化和配置代码，以及中断处理逻辑。
    此更新为系统添加了对USART1的支持，并实现了相关的中断处理函数。这些更改将允许系统通过USART1进行串口通信，并处理中断事件。
    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
2024-07-22 feat(USART): 1. 切换USART2接收方式为IT中断，DMA中断似乎有冲突 2. 更新huart1接口，测试完毕 将USART2的接收方式从DMA切换为IT中断，以优化中断处理并降低系统资源消耗。 此外，删除了未使用的HAL_UART_RxCpltCallback函数，并在HAL_UARTEx_RxEventCallback中 重新启动IT中断接收，确保连续监听串口数据。
    BREAKING CHANGE: 此更改影响到USART2的接收机制，任何依赖于DMA接收的代码都需要
    进行相应的调整以适应IT中断接收。
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2024-07-22 // BUG “”“引入vofa发送api”“”但似乎存在发送问题 （太困了今晚先睡了:poop:）
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2024-07-23 feat(uart): update HAL_UART callback function and add test comments
    Update the HAL_UART callback function prototype in usart.h and align the code
    style for better readability. Add comments for test purposes and initialize DMA
    transmission in usart.c.
    BREAKING CHANGE: The HAL_UART_MspInit and HAL_UART_MspDeInit functions have been
    modified to include additional checks for UART handle instances. This may affect
    existing code that relies on the previous implementation.
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2024-07-23 fix(usart): ```BUG```提交了一些BUG声明方便索引
    BUG DMA模式下似乎有问题
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2024-07-23 feat: 新增监工脚本
    Message body 用来查看加班强度:stuck_out_tongue_winking_eye:
    Message footer :innocent:
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2024-07-24 refactor(core): optimize clock configuration and update MPU settings
    Optimize the system clock configuration to enhance the system's performance and
    stability. The changes include refining the voltage scaling configuration and
    optimizing the clock divider settings for various buses.
    Additionally, update the MPU configuration to improve memory protection and
    system security. The MPU setup is now streamlined to ensure that the regions
    are enabled and configured with the required settings.
    BREAKING CHANGE: The updated clock configuration and MPU settings might affect
    existing peripheral configurations that rely on the previous clock settings.
    It is essential to review and adjust any periphera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
2024-08-20 ``` fix(.gitignore): 删除CMakeLists.txt中的空行
    CMakeLists.txt文件中存在额外的空行导致.gitignore文件。此次提交通过移除这些不必要的空行，确保.gitignore文件的准确性。
    ```
2024-10-15 删除其他分支代码，只保留计算平台
    [一帧数据.csv, 供电板板框.DXF]
2024-10-15 恢复main分支
    [一帧数据.csv, 供电板板框.DXF]
2024-10-15 删除其他分支代码，只保留计算分支代码
    [一帧数据.csv, 供电板板框.DXF]
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2024-10-15 新增算法说明文档，详细描述图像处理和车道检测流程
    - 文档涵盖图像预处理、分割方法、车道特征提取和注意事项等部分
    - 详细列出车道特征提取的方法和拟合技术
    - 强调了常见的问题及解决方案，如数据点映射回图像时的尺寸错误
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2024-10-15 修正RANSAC直线拟合的端点坐标获取
    在RANSAC拟合直线的代码中，修改了获取拟合直线两个端点的方式。通过使用`.item()`方法将PyTorch张量转换为Python标量，确保了端点坐标的正确计算和后续绘制直线操作的正常执行。
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2024-10-15 新增基于YOLOv8的实例分割骨架化处理 ```规范代码结构，基本确定使用骨架化方法 ``` 实现了对视频中物体的实例分割并进行骨架化处理。主要功能包括： - 使用YOLOv8模型进行物体检测和分割。 - 对分割出的掩码进行骨架化处理，提取骨架点坐标。 - 在原视频帧上绘制骨架点和分割结果。 - 实现了ROI（感兴趣区域）设置，提高处理效率。 - 支持调整掩码尺寸以适应原始视频帧大小。
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2024-10-16 重构代码结构，优化功能实现，新增系统监控工具
    - 重构了原有的 RANSAN_lane.py 代码，提高了代码的模块化和可读性
    - 新增了 CPU_GPU_stat.py 文件，实现了系统 CPU 和 GPU 使用情况的实时监控
    - 新增了 CPU_stat.py 文件，专门用于监控 CPU 的使用情况
    - 新增了 GPU_stat.py 文件，用于监控 GPU 的使用情况
2024-10-16 ``` ✔ 完成视频接口 ``` ```✨扩展视频处理支持网络流```，增加线程安全处理
    - 新增 VideoStream 类支持网络视频流拉取，使用线程读取视频数据
    - 扩展 VideoProcessor 类支持摄像头、网络流和视频文件输入
    - 优化 VideoProcessor 类的 read_frame 方法，支持不同视频源
    - 增加 VideoProcessor 类的 release 方法，确保正确释放资源
    - 主函数中使用 VideoProcessor 类处理视频源
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2024-10-16 ```重构代码以支持网络视频流```处理并优化视频源配置
    - 引入网络视频流处理，支持 HTTP/HTTPS URL 作为输入源
    - 重构 VideoProcessor 类，增加对网络流的支持
    - 添加 VideoStream 类，专门处理网络视频流的获取
    - 优化代码结构，提高对不同视频源的处理灵活性
    - 删除了一些不必要的绘制代码，简化了主处理流程
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2024-10-17 文档添加推理性能优化方法
    - 优化YOLO模型推理，建议使用批量推理或模型预热
    - 提高网络视频流处理效率，推荐使用异步IO库
    - 修正YOLOProcessor类中模型参数的设置方式
    - 使用OpenCV细化算法替代skimage骨架提取，提高效率
    -
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2024-10-17 ```增加小线段过滤，使拟合线更稳定``` ``` ⭕二项式拟合效果依旧不够精确，可以考虑机器学习ML方法``` 重构代码结构，优化功能实现，增加网络视频流支持
    - 将代码按功能模块化，提高可读性和可维护性
    - 引入多线程处理网络视频流，支持网络摄像头和视频流
    - 优化图像处理算法，提高车道线检测的准确性
    - 增加配置类，方便参数管理和调整
    - 重构视频处理逻辑，支持多种视频输入源
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2024-10-19 ```提取出精炼版本的控制代码``` ```❗CH100进程需要优化，ZMQ消息堵塞```chore: 更新 .gitignore 文件
    - 添加 cache.md 文件到忽略列表
    - 添加 Python 缓存文件夹 __pycache__ 到忽略列表
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2024-10-20 ```✨标记了CORE点，CH100进程卡顿是因为zmq缓冲区大小和IMU数据量不匹配```
    refactor(src): 优化数据读取缓冲区大小
    - ```将 read_and_parse 方法中的数据读取缓冲区大小从 1024 调整为 82```
    - 此修改旨在提高数据读取效率，减少不必要的内存占用
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2024-10-20 feat(config): 为 CH100 和 ODrive 设备添加 ZMQ 端口配置 从json中读取ZMQ端口配置而不是单独读取 - 在 config.json 中添加了 ch100 和 odrive 的 zmq_port 配置项 - 更新了 main.py 中的 ZMQPublisher 初始化，使用新的配置项 - 修改了 self_check.py 中的端口检查逻辑，动态收集并检查 Z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
2024-10-20 feat(test): 重构端口检查逻辑并添加电机控制 UI
    - 重构了 test_tcp_port.py 中的端口检查逻辑，使用 JSON 配置文件
    - 新增 motor_control_ui.py 文件，实现了一个电机控制的图形用户界面
    - 使用 PyQt5 创建了一个具有连接控制、电机位置和速度控制以及反馈显示的窗口
    - 添加了与 ODrive 协议的交互功能
2024-10-20 feat: 移动文件
    - 新增 motor_control_ui.py 文件实现电机控制的图形界面
    - 使用 PyQt5 创建窗口、按钮、滑动条等界面元素
    - 实现电机连接、位置控制、速度控制、看门狗更新等功能
    - 添加反馈标签显示当前电机状态或错误信息
    - 设定暗黑主题样式，提升用户体验
2024-10-20 feat(tools): 添加端口管理和监控工具
    - 新增 kill_process.py 脚本，用于结束占用指定端口的进程
    - 新增 monitor_ports.py 脚本，用于监测指定端口的使用情况
    - 删除 motor_control_ui.py 文件，清理不再需要的电机控制界面代码
2024-10-20 ```✅完成数据从zmq平台订阅``` ```✅完成了CH100及Odrive线程优化``` ```⭕准备进行控制代码书写``` refactor(balance_control): 重构平衡控制模块并整合数据处理逻辑
    - 重构 balance_control 模块，改为 control_module.py
    - 新增 control_layer 函数处理不同类型设备数据
    - 在 main.py 中集成 control_layer 函数
    - 修改数据处理逻辑，提取并保存所需控制参数
    - 优化日志输出和变量命名，提高代码可读
2024-10-20 ```✅完成实例方法的传入，可以控制电机``` feat: 添加全局变量以共享 ODrive 实例
    - 增加全局变量 global_odrive 以便在不同线程中共享 ODrive 实例
    - 修改 odrive_thread_function 中的 ODrive 实例创建和使用全局变量
    - 此修改为后续的 PR 将在 ch100_thread_function 中使用 global_odrive 做准备
2024-10-21 feat(logging): 添加彩色日志功能
    - 新增 color_logger.py 文件实现彩色日志输出
    - 创建 HandleLog 类统一处理日志记录和输出
    - 支持将日志输出到控制台和文件
    - 可根据日志级别进行不同颜色的区分
2024-10-21 refactor(balance_control): 注释标记潜在bug
    在balance_control.py文件中，添加了注释标记潜在的bug。这个修改提醒开发者注意发送指令可能占用接口资源导致的问题。
    - 在发送电机速度更新指令的地方添加注释
    - 提示可能存在的资源占用问题
    [balance_control.py]
2024-10-21 refactor(odrive): 优化 ODrive 线程并添加注释
    - 将英文注释翻译为中文
    - 在 ODrive 线程中添加 ```10 毫秒的请求间隔```
    - 优化日志信息的中文表述
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2024-11-11 Revert "合并错误，不需要beta分支的计算平台代码"
    This reverts commit 44ae5a4c59af4cf17a272be7f092c20d0cfca8be.
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2024-11-18 fix: 修改文件名大小写 增加开发资料
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2024-11-19 docs(calculate_unit): 更新脉冲计算单元文档
    - 新增脉冲计算单元数据帧格式的 CSV 表格
    - 在文档中添加了字段描述和大小信息
    - 更新了数据传输层的描述
    - 添加了新的 Excel 文件以进一步说明脉冲计算单元
    [协议帧.csv, 帧协议.xlsx]
2024-11-19 fix: 修改文件名大小写
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2024-11-24 chore: 更新 .gitignore 文件
    - 修复 dataset 文件夹的忽略路径
    - 添加 _.md 文件到忽略列表
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2024-11-28 refactor(Calculation_Unit): 优化锥桶检测逻辑
    - 引入配置项 CONE_DET_COOLING_TIME 作为锥桶检测冷却时间
    - 使用配置项 AVOID_CONE_INDEX 判断是否切换到避障状态
    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
    [main.py]
2024-11-28 feat(config): 添加避障锥桶相关配置
    - 新增 AVOID_CONE_INDEX 配置项，用于指定需要避障的锥桶索引
    - 新增 CONE_DET_COOLING_TIME 配置项，用于设置锥桶检测冷却时间
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2024-11-28 fix(Calculation_Unit): 等待视频流准备好再开始处理
    - 添加初始化代码，确保在视频流可用时才开始处理帧
    - 实现 10 秒超时机制，防止无限等待
    [main.py]
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2024-11-28 fix Calculation_Unit: 优化避障功能并添加中点平滑滤波
    - 在 lane_process 函数中添加了对中点进行平滑滤波的 todo 事项
    - 在 process_avoid_obstacle 函数中增加了舵机回中值的操作
    - 修正了向左和向右打方向时发送的脉冲值，使其相对于中点对称
    [main.py]
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2024-11-28 feat(config): 更新锥桶检测配置并增加新的确认时间参数
    - 重命名 AVOID_CONE_INDEX 为 CONE_TO_AVOID_INDEX，提高变量命名的明确性
    - 新增 CONE_CONFIRMATION_DURATION 参数，用于确认锥桶所需的持续检测时间
    - 更新 main.py 中的相关逻辑，使用新的配置参数
    [main.py]
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2024-11-29 refactor(Calculation_Unit): 调整避障速度配置
    - 将固定的速度值 0.5 替换为 Config.AVOID_SPEED，以提高代码的可配置性和可维护性
    - 此修改有助于未来调整避障速度时不必直接修改源代码
    [main.py]
2024-11-29 feat(config): 添加避障类参数
    - 在 Config 类中添加了 AVOID_SPEED 和 AVOID_ANGLE 两个避障类参数
    - AVOID_SPEED 设置为 -0.5，AVOID_ANGLE 设置为 1
    - 这些参数用于避障功能的实现
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2024-11-29 refactor(Calculation_Unit): 更新模型路径和输入源
    - 更新 LANE_MODEL 和 ELEMENTS_MODEL 的路径
    - 更改 INPUT_SOURCE 为新的视频文件
    - 调整 ELEMENTS_CLASS_NAME 的顺序，将 "cone" 放到最后
    - 修正过滤得分的条件，使用 TURN_SIGN_CT 代替 ZEBRA_CT
    [main.py]
2024-11-29 refactor(config): 更新模型路径和优化配置参数
    - 调整 INPUT_SOURCE 格式
    - 优化任务类参数的组织结构
    - 修正 TURN_SIGN_CT 的引用
    - 在避障任务中添加 BUG 注释
    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
    [main.py]
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2024-12-03 Revert "Merge remote-tracking branch 'origin/Mechanical_Unit'"
    This reverts commit edb8d283a7e4bf32d372c66be2149ffb2f8888f1, reversing
    changes made to 65af83ac90ed2be4f1b07ff992eab9f2839ddaa1.
    [01摄像头部件.STL, 02 舵机支架.STL, 02舵机支架.STL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]
2024-12-03 ```✅增加合并机械结构```
    [01摄像头部件.STL, 02 舵机支架.STL, 02舵机支架.STL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]
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2026-10-17 修正了UI
2026-10-29 对 ODrive 速度测试和协议进行优化
    整理速度测试与参数调优脚本，修正停止停稳判定，并增强 ODrive ASCII 查询和速度指令处理。
2026-10-29 修正 UI 电机停止流程并补充测试
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
